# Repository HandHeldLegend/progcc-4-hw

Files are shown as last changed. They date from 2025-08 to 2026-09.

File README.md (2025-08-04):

# progcc-4-hw
Official repository for ProGCC 4 Hardware.

## 3D Models License
<br />The 3D CAD files are licensed under a <a rel="license" href="http://creativecommons.org/licenses/by/4.0/">Creative Commons Attribution 4.0 International License</a>.

## Schematic and PCB License
<br />This PCB and electronic schematic are licensed under a <a rel="license" href="http://creativecommons.org/licenses/by-nc-sa/3.0/">Creative Commons Attribution-NonCommercial-ShareAlike 3.0 Unported License</a>.

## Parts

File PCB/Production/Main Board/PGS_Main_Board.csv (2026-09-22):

Reference | Qty | Value | Footprint | Manufacturer | MPN | DNP | LCSC
C1,C2 | 2 | 15pF | Capacitor_SMD:C_0402_1005Metric | YAGEO | CC0402FRNPO9BN150 |  | C326803
C3,C4,C5,C6,C7,C8,C17,C18,C19,C29,C30,C31,C32,C33,C34,C35,C36,C37,C38 | 19 | 100n | Capacitor_SMD:C_0201_0603Metric | muRata | GRM033R61A104KE15D |  | C76934
C9,C10,C24,C25,C26,C27 | 6 | 100nF | Capacitor_SMD:C_0201_0603Metric | Samsung Electro-Mechanics | CL03A104KQ3NNNC |  | C160831
C11,C12,C13,C14 | 4 | 1uF | Capacitor_SMD:C_0201_0603Metric | Murata Electronics | GRM033R60J105KEA2D |  | C76929
C23,C39,C40,C41 | 4 | 4.7u | Capacitor_SMD:C_0402_1005Metric | Samsung Electro-Mechanics | CL05A475KP5NRNC |  | C368809
D1,D2,D3,D4,D5,D6 | 6 | M7C | Diode_SMD:D_SOD-523 | LGE | B5819WT |  | C5364321
J1,J2 | 2 | SM02B-SURS-TF_LF__SN_ | hhl:JST_SM02B-SURS-TF_LF__SN_ | JST | SM02B-SURS-TF(LF)(SN) |  | C566239
J3,J5 | 2 | Molex 505110-0892 | hhl:5051100892 | MOLEX | 505110-0892 |  | C5902847
J7,J11 | 2 | Molex 505110-0592 | hhl:5051100592 | MOLEX | 505110-0592 |  | C3168457
J9 | 1 | Molex 505110-1792 | hhl:5051101792 | MOLEX | 505110-1792 |  | C6819458
L1 | 1 | 3.3u | hhl:L_pol_2016 | Abraco LLC | AOTA-B201610S3R3-101-T |  | C42411119
Q1,Q2 | 2 | MMBT2222A | Package_TO_SOT_SMD:SOT-23 | JSMSEMI | MMBT2222A |  | C916372
R1,R28,R29 | 3 | 1k | Resistor_SMD:R_0201_0603Metric | YAGEO
R3,R4,R12,R13,R14,R15,R16,R17,R18,R21,R22,R25,R26,R30,R31,R33,R34 | 17 | 27R | Resistor_SMD:R_0201_0603Metric | YAGEO | RC0201FR-0727RL |  | C273268
R5,R6 | 2 | 10k | Resistor_SMD:R_0201_0603Metric | YAGEO
R7,R8 | 2 | 100R | Resistor_SMD:R_0201_0603Metric | YAGEO
R9,R10 | 2 | 10R | Resistor_SMD:R_0201_0603Metric | YAGEO
R11 | 1 | 33 | Resistor_SMD:R_0201_0603Metric | YAGEO
RGB1,RGB2,RGB3,RGB4,RGB5,RGB6,RGB7,RGB8,RGB9,RGB10,RGB11,RGB12,RGB13,RGB14,RGB15,RGB16 | 16 | SK6805-EC-10 | hhl:SK6805-EC-10 | OPSCO Optoelectronics | SK6805-EC-10 |  | C22394946
SW3,SW4,SW5,SW6,SW7,SW8,SW9,SW10,SW11 | 9 | SW_Push | hhl:KSC-TE | C&K | KSC201J LFS |  | C221725
U1,U3,U6,U7,U8,U9,U10,U11 | 8 | HAL4395 | hhl:SOT-23-5L | Hallwee | HAL4395SO5 |  | C49165022
U2 | 1 | RP2350_80QFN | hhl:RP2350-QFN-80-1EP_10x10_P0.4mm_EP3.4x3.4mm_ThermalVias | Raspberry Pi | RP2354B |  | C39843328
U4,U5 | 2 | ST_LSM6 | hhl:LGA14 | STMicroelectronics | LSM6DSLTR |  | C126672
Y1 | 1 | ABM8-272-T3 | Crystal:Crystal_SMD_3225-4Pin_3.2x2.5mm | Abracon LLC | ABM8-272-T3 |  | C20625731

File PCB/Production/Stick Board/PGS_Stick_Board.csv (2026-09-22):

Reference | Qty | Value | Footprint | Manufacturer | MPN | LCSC | DNP
C1,C2 | 2 | 47nF | Capacitor_SMD:C_0402_1005Metric | YAGEO | CC0402KRX7R9BB473 | C272875
J1 | 1 | Molex 505110-0892 | hhl:5051100892 | MOLEX | 505110-0892 | C5902847
R1,R2 | 2 | 1k | Resistor_SMD:R_0201_0603Metric | YAGEO | RC0201FR-071KL | C138165
RGB1,RGB2,RGB3,RGB4 | 4 | SK6805-EC-10 | hhl:SK6805-EC-10 | OPSCO Optoelectronics | SK6805-EC-10 | C22394946
SW1 | 1 | GL1807SYAE-002 | hhl:GL1807SYAE | Gulikit | GL1807SYAE-002

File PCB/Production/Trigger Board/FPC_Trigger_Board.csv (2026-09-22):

Reference | Qty | Value | Datasheet | Footprint | Manufacturer | MPN | LCSC | DNP
C1,C2,C3,C4 | 4 | 100n |  | Capacitor_SMD:C_0201_0603Metric | muRata | GRM033R61A104KE15D | C76934
J1,J2 | 2 | Conn_01x05_Pin |  | hhl:505110-0592 Ribbon |  |  |  | DNP
U1,U2,U3,U4 | 4 | HAL4395 | https://www.lcsc.com/datasheet/C49165022.pdf | hhl:SOT-23-5L | Hallwee | HAL4395SO5 | C49165022

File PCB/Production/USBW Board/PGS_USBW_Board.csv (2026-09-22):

Reference | Qty | Value | Footprint | Manufacturer | MPN | LCSC | DNP | Reviewed
C1 | 1 | 47uF | Capacitor_Tantalum_SMD:CP_EIA-3216-18_Kemet-A | Kyocera AVX | TAJA476K006RNJ | C7190 |  | Yes
C2,C4 | 2 | 10uF | Capacitor_SMD:C_0805_2012Metric | Samsung Electro-Mechanics | CL21A106KPFNNNE | C17024 |  | Yes
C3 | 1 | 100nF | Capacitor_SMD:C_0201_0603Metric | Samsung Electro-Mechanics | CL03A104KQ3NNNC | C160831 |  | Yes
C7,C14 | 2 | 1uF | Capacitor_SMD:C_0201_0603Metric | Murata Electronics | GRM033R60J105KEA2D | C76929 |  | Yes
C15 | 1 | 0.47uF | Capacitor_SMD:C_0201_0603Metric | Murata Electronics | GRM033R60J474KE90D | C85926 |  | Yes
D1,D3,D4 | 3 | CUS08F30,H3F | Diode_SMD:D_SOD-323_HandSoldering | TOSHIBA | CUS08F30,H3F | C150183 |  | Yes
IC1 | 1 | BQ27621YZFR-G1A | hhl:BGA9C50P3X3_162X158X62 | Texas Instruments | BQ27621YZFR-G1A | C544417 |  | Yes
J1 | 1 | Molex 505110-1792 | hhl:5051101792 | MOLEX | 505110-1792 | C6819458 |  | Yes
J2 | 1 | USB4056-03-A | hhl:USB405603A | Global Connector Technology | USB4056-03-A | C7407280 |  | Yes
J4 | 1 | PH 2.0 JST | Connector_JST:JST_PH_B2B-PH-K_1x02_P2.00mm_Vertical | JST | B2B-PH-K-K(LF)(SN) | C265438 |  | Yes
L1 | 1 | 1.3A 2.2uH ±20% 80mΩ | Inductor_SMD:L_1008_2520Metric | INPAQ | MIP25202R2MBE | C315721 |  | Yes
L2 | 1 | BLM18AG601SN1D | Inductor_SMD:L_0603_1608Metric | Murata Electronics | BLM18AG601SN1D | C19330 |  | Yes
P1 | 1 | RPI-RM2 | hhl:RPI_RM2 | Raspberry Pi | RPI-RM2
Q1,Q2 | 2 | BSS138DW | Package_TO_SOT_SMD:SOT-363_SC-70-6 | Diodes Incorporated | BSS138DW-7-F | C154900 |  | Yes
R1,R2 | 2 | 5.1k | Resistor_SMD:R_0201_0603Metric | YAGEO | RC0201FR-075K1L | C274341 |  | Yes
R3,R4,R5,R6,R7,R8 | 6 | 1k | Resistor_SMD:R_0201_0603Metric | YAGEO | RC0201FR-071KL | C138165 |  | Yes
R9 | 1 | 100R | Resistor_SMD:R_0201_0603Metric | YAGEO | RC0201FR-07100RL | C77623 |  | Yes
R10 | 1 | 0R | Resistor_SMD:R_0201_0603Metric | YAGEO | RC0201FR-070RL | C106227 |  | Yes
R12,R13,R20,R29 | 4 | 10k | Resistor_SMD:R_0201_0603Metric | YAGEO | RC0201FR-0710KL | C106225 |  | Yes
R14 | 1 | 470R | Resistor_SMD:R_0201_0603Metric | YAGEO | AC0201FR-07470RL | C226558 |  | Yes
R38 | 1 | 100k | Resistor_SMD:R_0402_1005Metric |  | RC0402FR-07100KL | C60491
U1,U2,U3 | 3 | USBLC6-2P6 | Package_TO_SOT_SMD:SOT-666 | TECH PUBLIC | USBLC6-2P6 | C2827693 |  | Yes
U5 | 1 | BQ25180 | hhl:DSBGA | Texas Instruments | BQ25180YBGR | C3682423 |  | Yes
U4 | 1 | TPS63001DRCR | hhl:VREG_V62_16624-01YE | Texas Instruments | TPS63001DRCR | C28060 |  | Yes

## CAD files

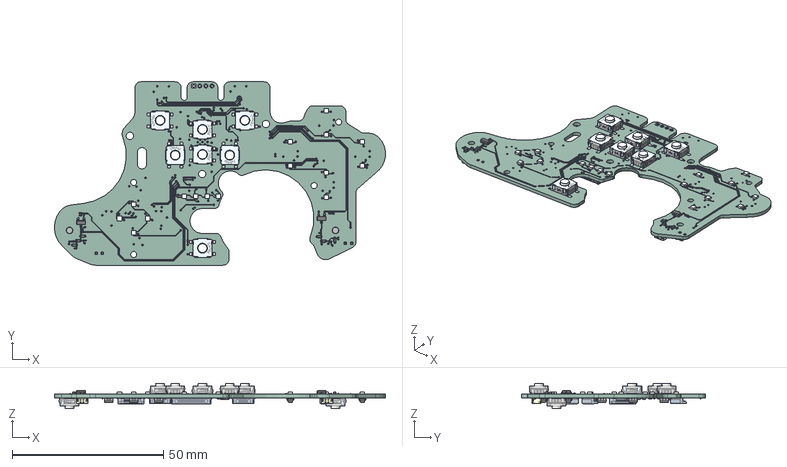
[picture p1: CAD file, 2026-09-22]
3D/PCB/PGS_Main_Board.step
109.5 x 60.7 x 8.33 mm
R_0201_0603Metric x 27
SK6805-EC15-3D v2 x 16
D_SOD_523 x 6
KSC2TE01JLFS_PART1 x 9
C_0201_0603Metric x 29
SOT-23 x 2
C_0402_1005Metric x 6
SOT-23-5 x 8
SM02B-SURS-TF(LF)(SN) x 2
Crystal_SMD_3225-4Pin_3.2x2.5mm
PGS_Main_Board_copper
PGS_Main_Board_pad
PGS_Main_Board_via
PGS_Main_Board_PCB

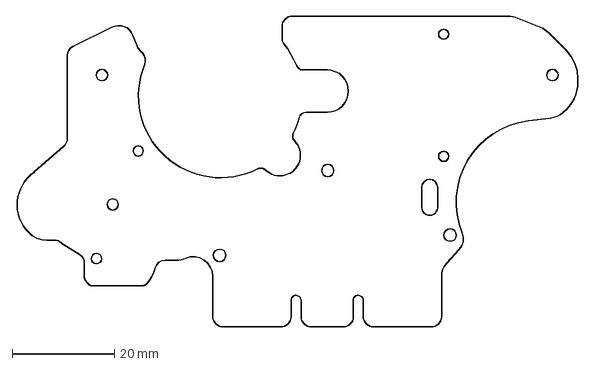
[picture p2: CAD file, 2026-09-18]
PCB/Outlines/Main_PCB_Outline.dxf
109.7 x 60.7 mm

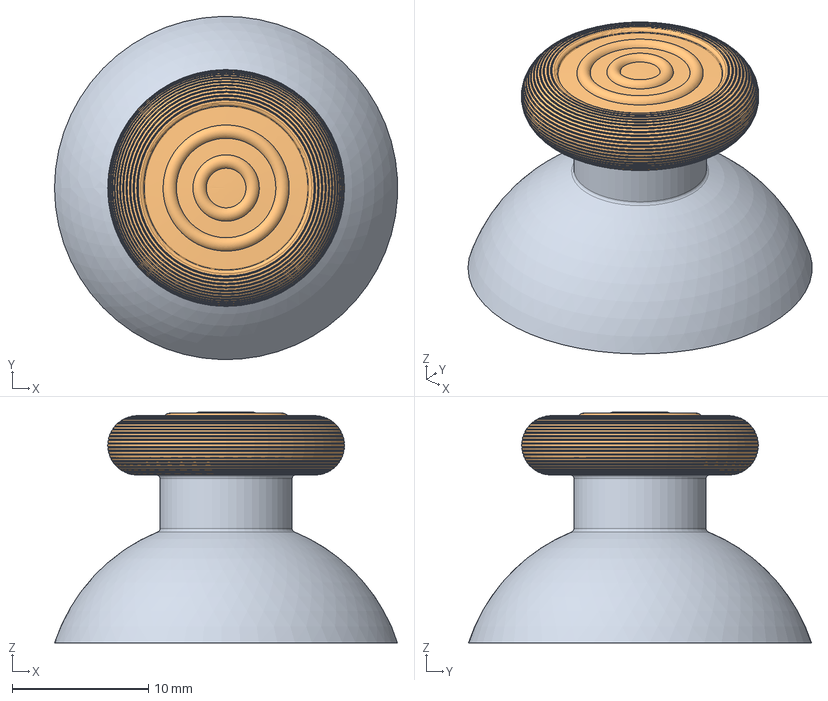
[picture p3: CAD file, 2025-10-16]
3D/Joystick/FullStick.step
25.1 x 25.1 x 16.9 mm
PlasticPart
RubberPart

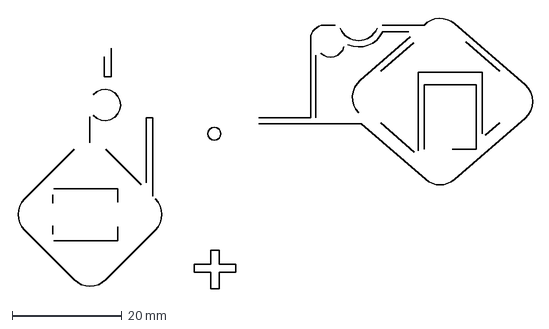
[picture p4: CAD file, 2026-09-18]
PCB/Outlines/Main_PCB_Keepout_Back.dxf
94.0 x 49.7 mm

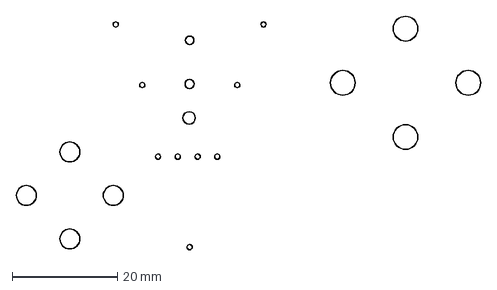
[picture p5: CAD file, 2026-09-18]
PCB/Outlines/Main_PCB_Components.dxf
88.1 x 44.3 mm

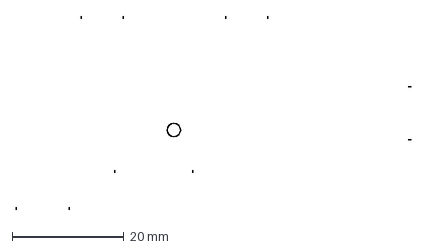
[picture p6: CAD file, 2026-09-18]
PCB/Outlines/Main_PCB_Connectors.dxf
70.7 x 34.7 mm

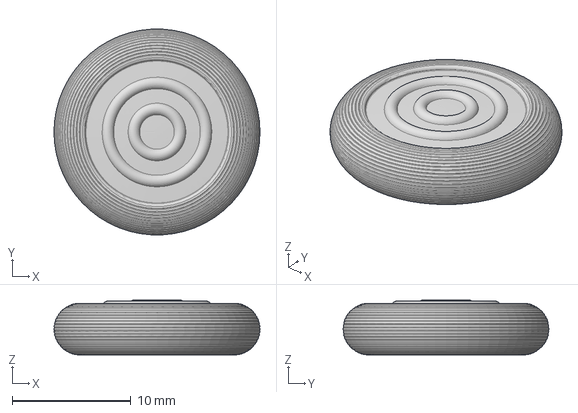
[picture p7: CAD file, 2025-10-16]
3D/Joystick/RubberPart.step
17.3 x 17.3 x 4.62 mm

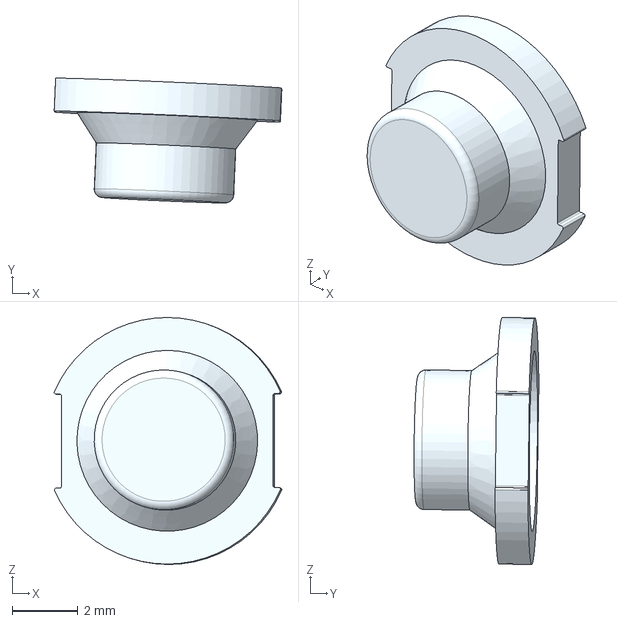
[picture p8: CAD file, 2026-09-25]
3D/STEP/Silicone Trigger (4pc needed).step
6.93 x 3.80 x 7.51 mm

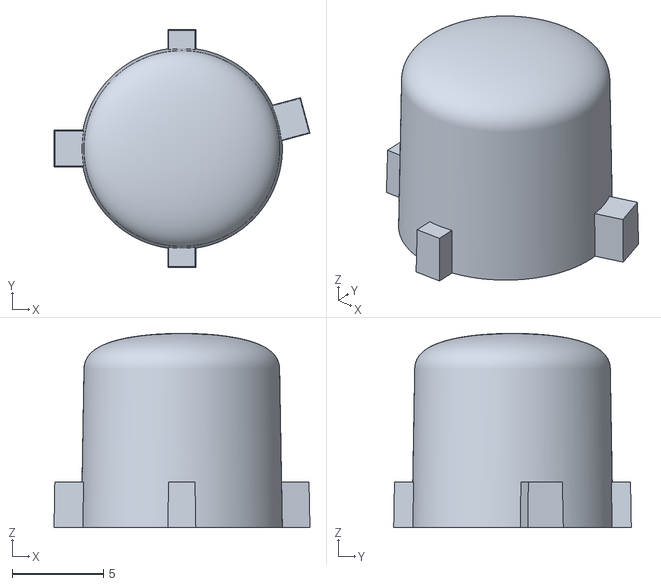
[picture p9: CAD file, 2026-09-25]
3D/STL/Button West Body.stl
14.0 x 13.0 x 10.6

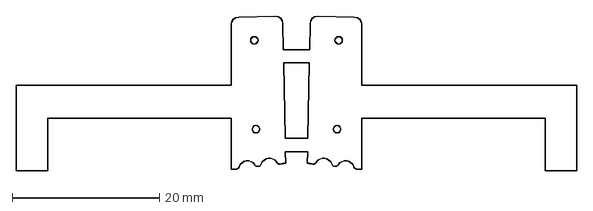
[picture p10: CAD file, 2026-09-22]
PCB/Outlines/Trigger OutlinePlace.dxf
76.2 x 21.0 mm

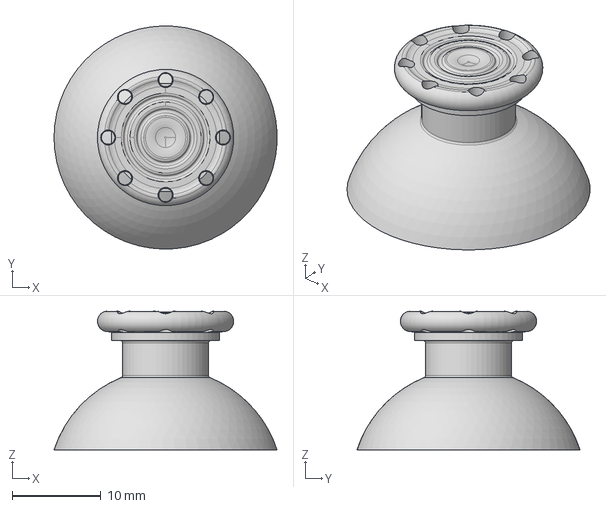
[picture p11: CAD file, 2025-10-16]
3D/Joystick/PlasticPart.step
25.1 x 25.1 x 15.6 mm

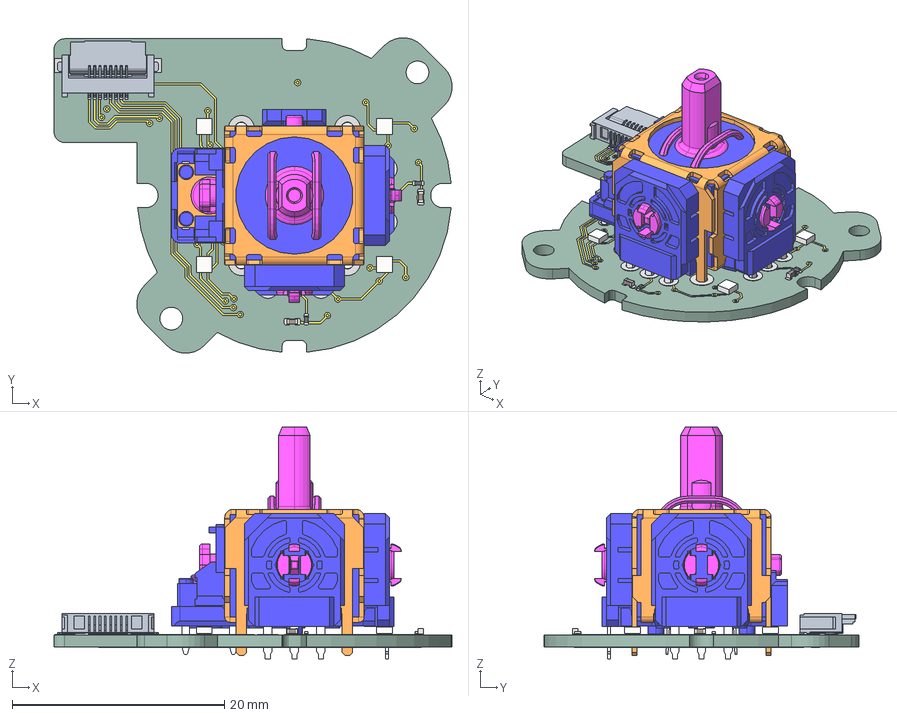
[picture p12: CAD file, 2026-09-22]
3D/PCB/PGS_Stick_Board.step
37.5 x 29.7 x 21.9 mm
SK6805-EC15-3D v2 x 4
R_0201_0603Metric x 2
C_0402_1005Metric x 2
PGSAFB4_copper
PGSAFB4_pad
PGSAFB4_via
PGSAFB4_PCB

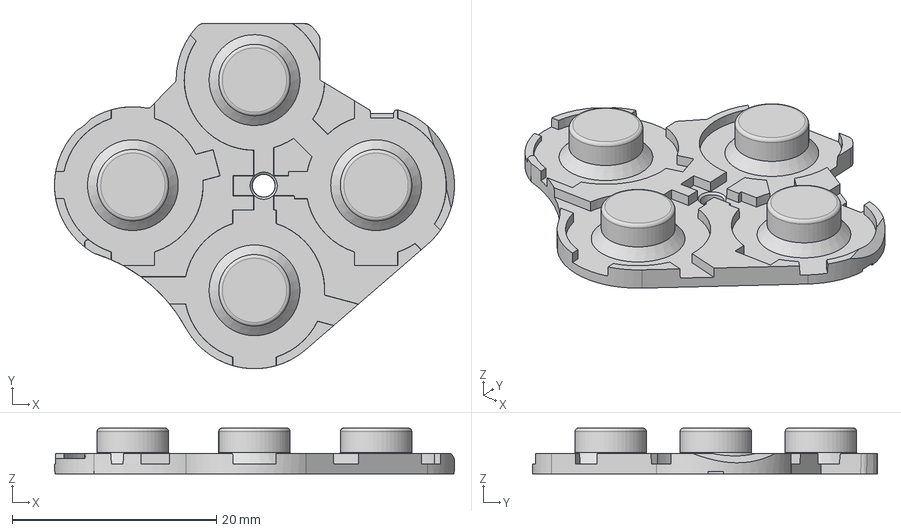
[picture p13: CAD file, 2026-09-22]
3D/STEP/Silicone SEWN.step
39.1 x 33.8 x 4.50 mm

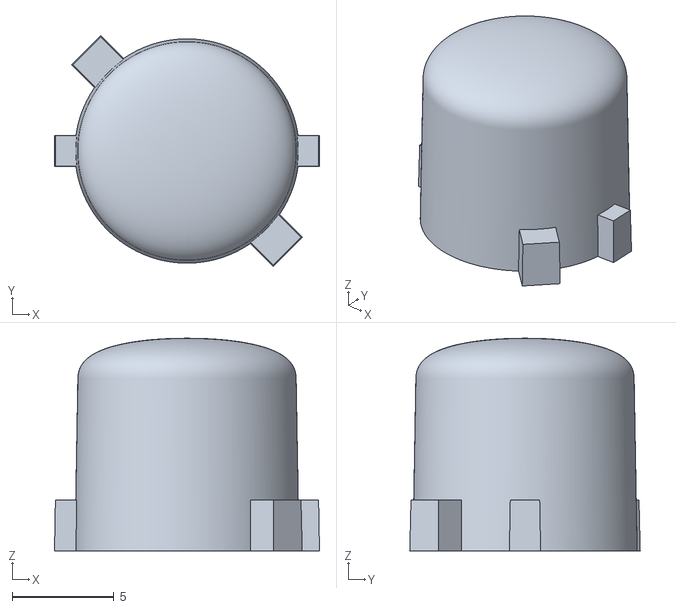
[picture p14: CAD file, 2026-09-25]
3D/STL/Button North Body.stl
13.0 x 11.3 x 10.5

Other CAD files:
3D/PCB/PGS_USBW_Board.step
3D/STEP/Silicone DPad.step
3D/STL/DPad Body.stl
3D/STL/Button South Body.stl
3D/Joystick/FullStick.iges
3D/Joystick/PlasticPart.iges
3D/Joystick/RubberPart.iges
3D/STL/Button East Body.stl
3D/STL/GL Button.stl
3D/STL/GR Button.stl
3D/STL/Gateplate Octagonal.stl
3D/STL/Gateplate Round.stl
3D/STL/Menu Button.stl
3D/STL/Player Lightpipe.stl
3D/STL/Power Button.stl
3D/STL/Shell Lower Body.stl
3D/STL/Shell Middle Body.stl
3D/STL/Shell Top Body.stl
3D/STL/Support Frame.stl
3D/STL/Trigger Bracket.stl
3D/STL/Triggers Body.stl
PCB/Outlines/Stick_Module_Export.dxf
PCB/Outlines/Trigger_Board_Export.dxf
PCB/Outlines/USB_Board_Export.dxf

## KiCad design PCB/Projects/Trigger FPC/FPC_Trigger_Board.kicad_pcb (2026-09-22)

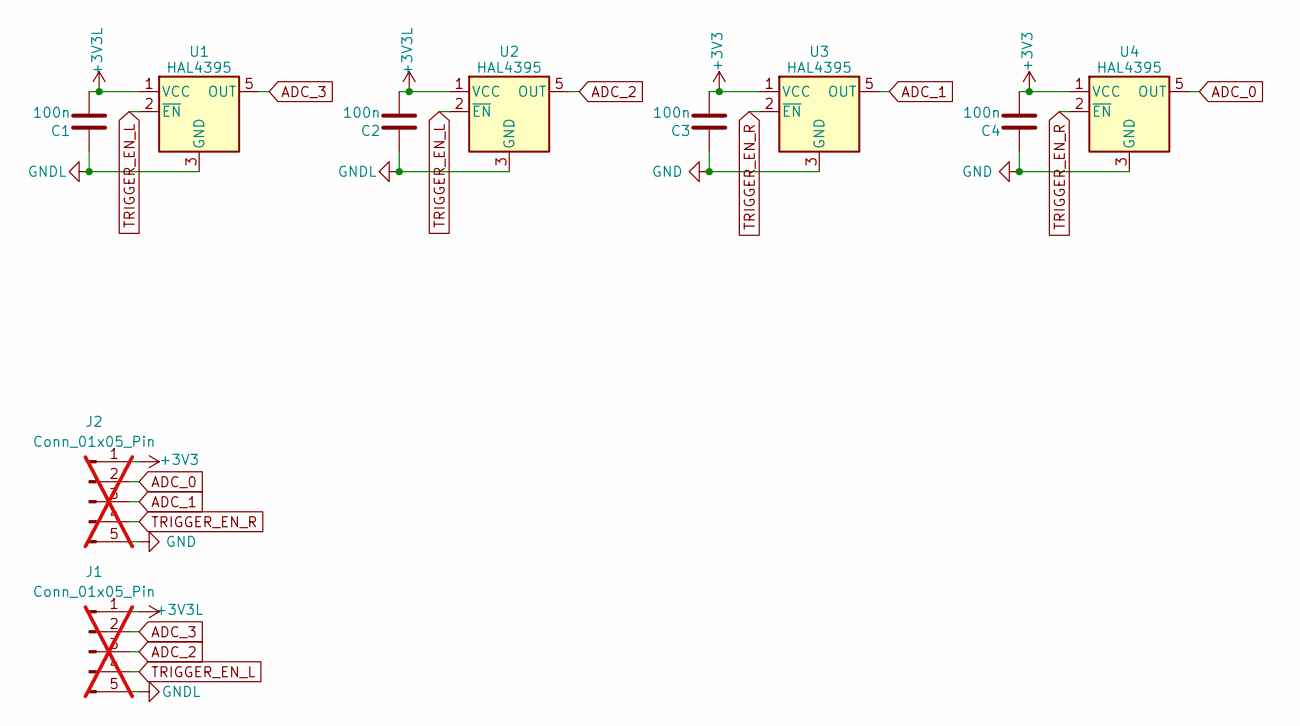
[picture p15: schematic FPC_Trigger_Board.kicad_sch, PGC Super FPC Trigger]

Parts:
C1, C2, C3, C4: 100n; C_0201_0603Metric; MPN GRM033R61A104KE15D; LCSC C76934
J1, J2: Conn_01x05_Pin; 505110-0592 Ribbon; not fitted
U1, U2, U3, U4: HAL4395; SOT-23-5L; MPN HAL4395SO5; LCSC C49165022

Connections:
+3V3: C3.2, C4.2, J2.1, U3.1 (VCC), U4.1 (VCC)
+3V3L: C1.2, C2.2, J1.1, U1.1 (VCC), U2.1 (VCC)
ADC_0: J2.2, U4.5 (OUT)
ADC_1: J2.3, U3.5 (OUT)
ADC_2: J1.3, U2.5 (OUT)
ADC_3: J1.2, U1.5 (OUT)
GND: C3.1, C4.1, J2.5, U3.3 (GND), U4.3 (GND)
GNDL: C1.1, C2.1, J1.5, U1.3 (GND), U2.3 (GND)
TRIGGER_EN_L: J1.4, U1.2 (~EN), U2.2 (~EN)
TRIGGER_EN_R: J2.4, U3.2 (~EN), U4.2 (~EN)

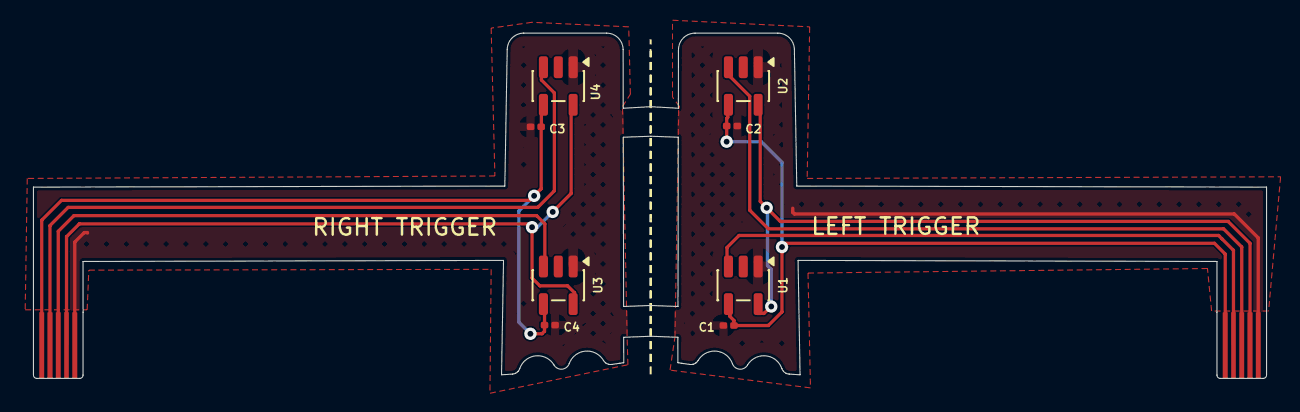
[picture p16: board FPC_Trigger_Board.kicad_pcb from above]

Board: 2 copper layers, 74.6 x 20.9 mm, 10 parts (2 on the bottom side), 10 nets.

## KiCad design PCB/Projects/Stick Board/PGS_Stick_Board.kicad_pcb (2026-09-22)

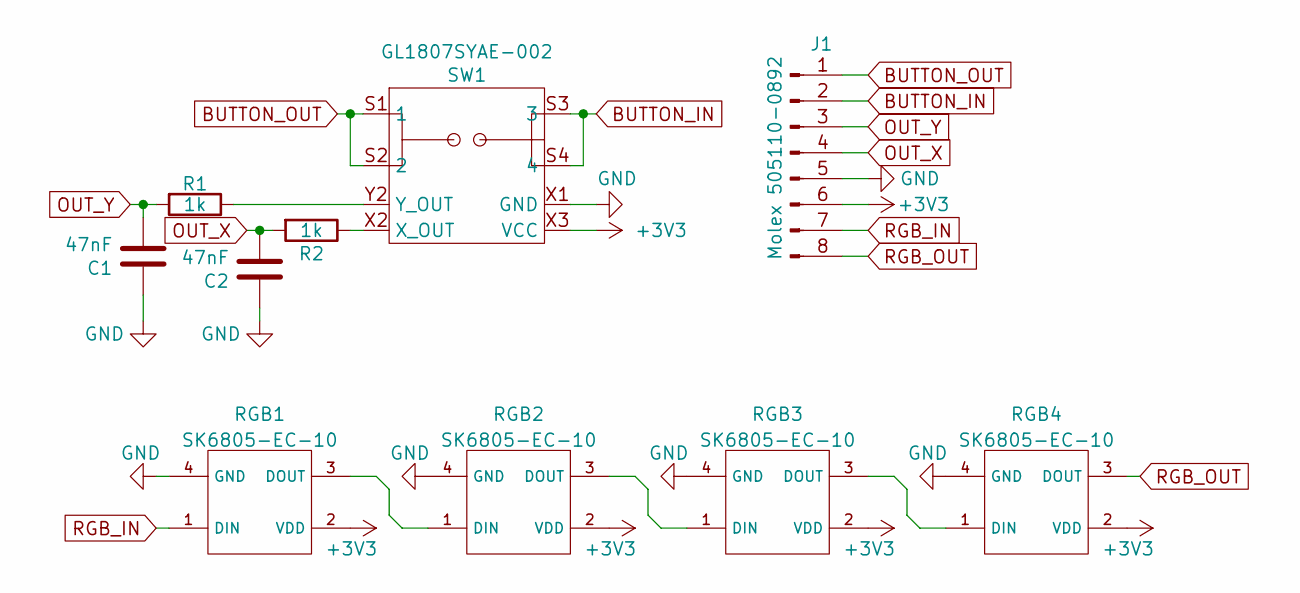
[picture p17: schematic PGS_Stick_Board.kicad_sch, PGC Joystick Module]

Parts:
C1, C2: 47nF; C_0402_1005Metric; MPN CC0402KRX7R9BB473; LCSC C272875
J1: Molex 505110-0892; 5051100892; MPN 505110-0892; LCSC C5902847
R1, R2: 1k; R_0201_0603Metric; MPN RC0201FR-071KL; LCSC C138165
RGB1, RGB2, RGB3, RGB4: SK6805-EC-10; MPN SK6805-EC-10; LCSC C22394946
SW1: GL1807SYAE-002; GL1807SYAE; MPN GL1807SYAE-002

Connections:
+3V3: J1.6, RGB1.2 (VDD), RGB2.2 (VDD), RGB3.2 (VDD), RGB4.2 (VDD), SW1.X3 (VCC), SW1.Y3 (VCC)
BUTTON_IN: J1.2, SW1.S3 (3), SW1.S4 (4)
BUTTON_OUT: J1.1, SW1.S1 (1), SW1.S2 (2)
GND: C1.1, C2.1, J1.5, RGB1.4 (GND), RGB2.4 (GND), RGB3.4 (GND), RGB4.4 (GND), SW1.X1 (GND), SW1.Y1 (GND)
unnamed: RGB1.3 (DOUT), RGB2.1 (DIN)
unnamed: RGB2.3 (DOUT), RGB3.1 (DIN)
unnamed: RGB3.3 (DOUT), RGB4.1 (DIN)
unnamed: R2.1, SW1.X2 (X_OUT)
unnamed: R1.1, SW1.Y2 (Y_OUT)
OUT_X: C2.2, J1.4, R2.2
OUT_Y: C1.2, J1.3, R1.2
RGB_IN: J1.7, RGB1.1 (DIN)
RGB_OUT: J1.8, RGB4.3 (DOUT)

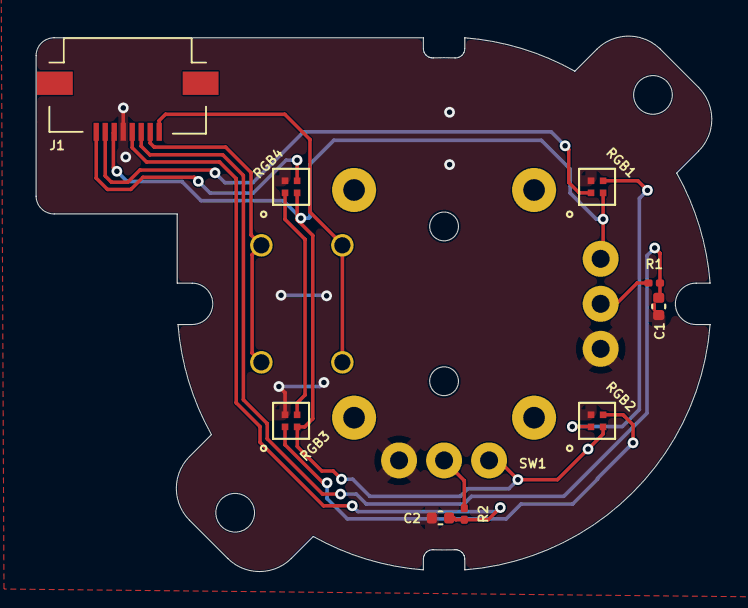
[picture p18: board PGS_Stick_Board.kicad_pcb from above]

Board: 2 copper layers, 37.5 x 29.7 mm, 10 parts (0 on the bottom side), 13 nets.

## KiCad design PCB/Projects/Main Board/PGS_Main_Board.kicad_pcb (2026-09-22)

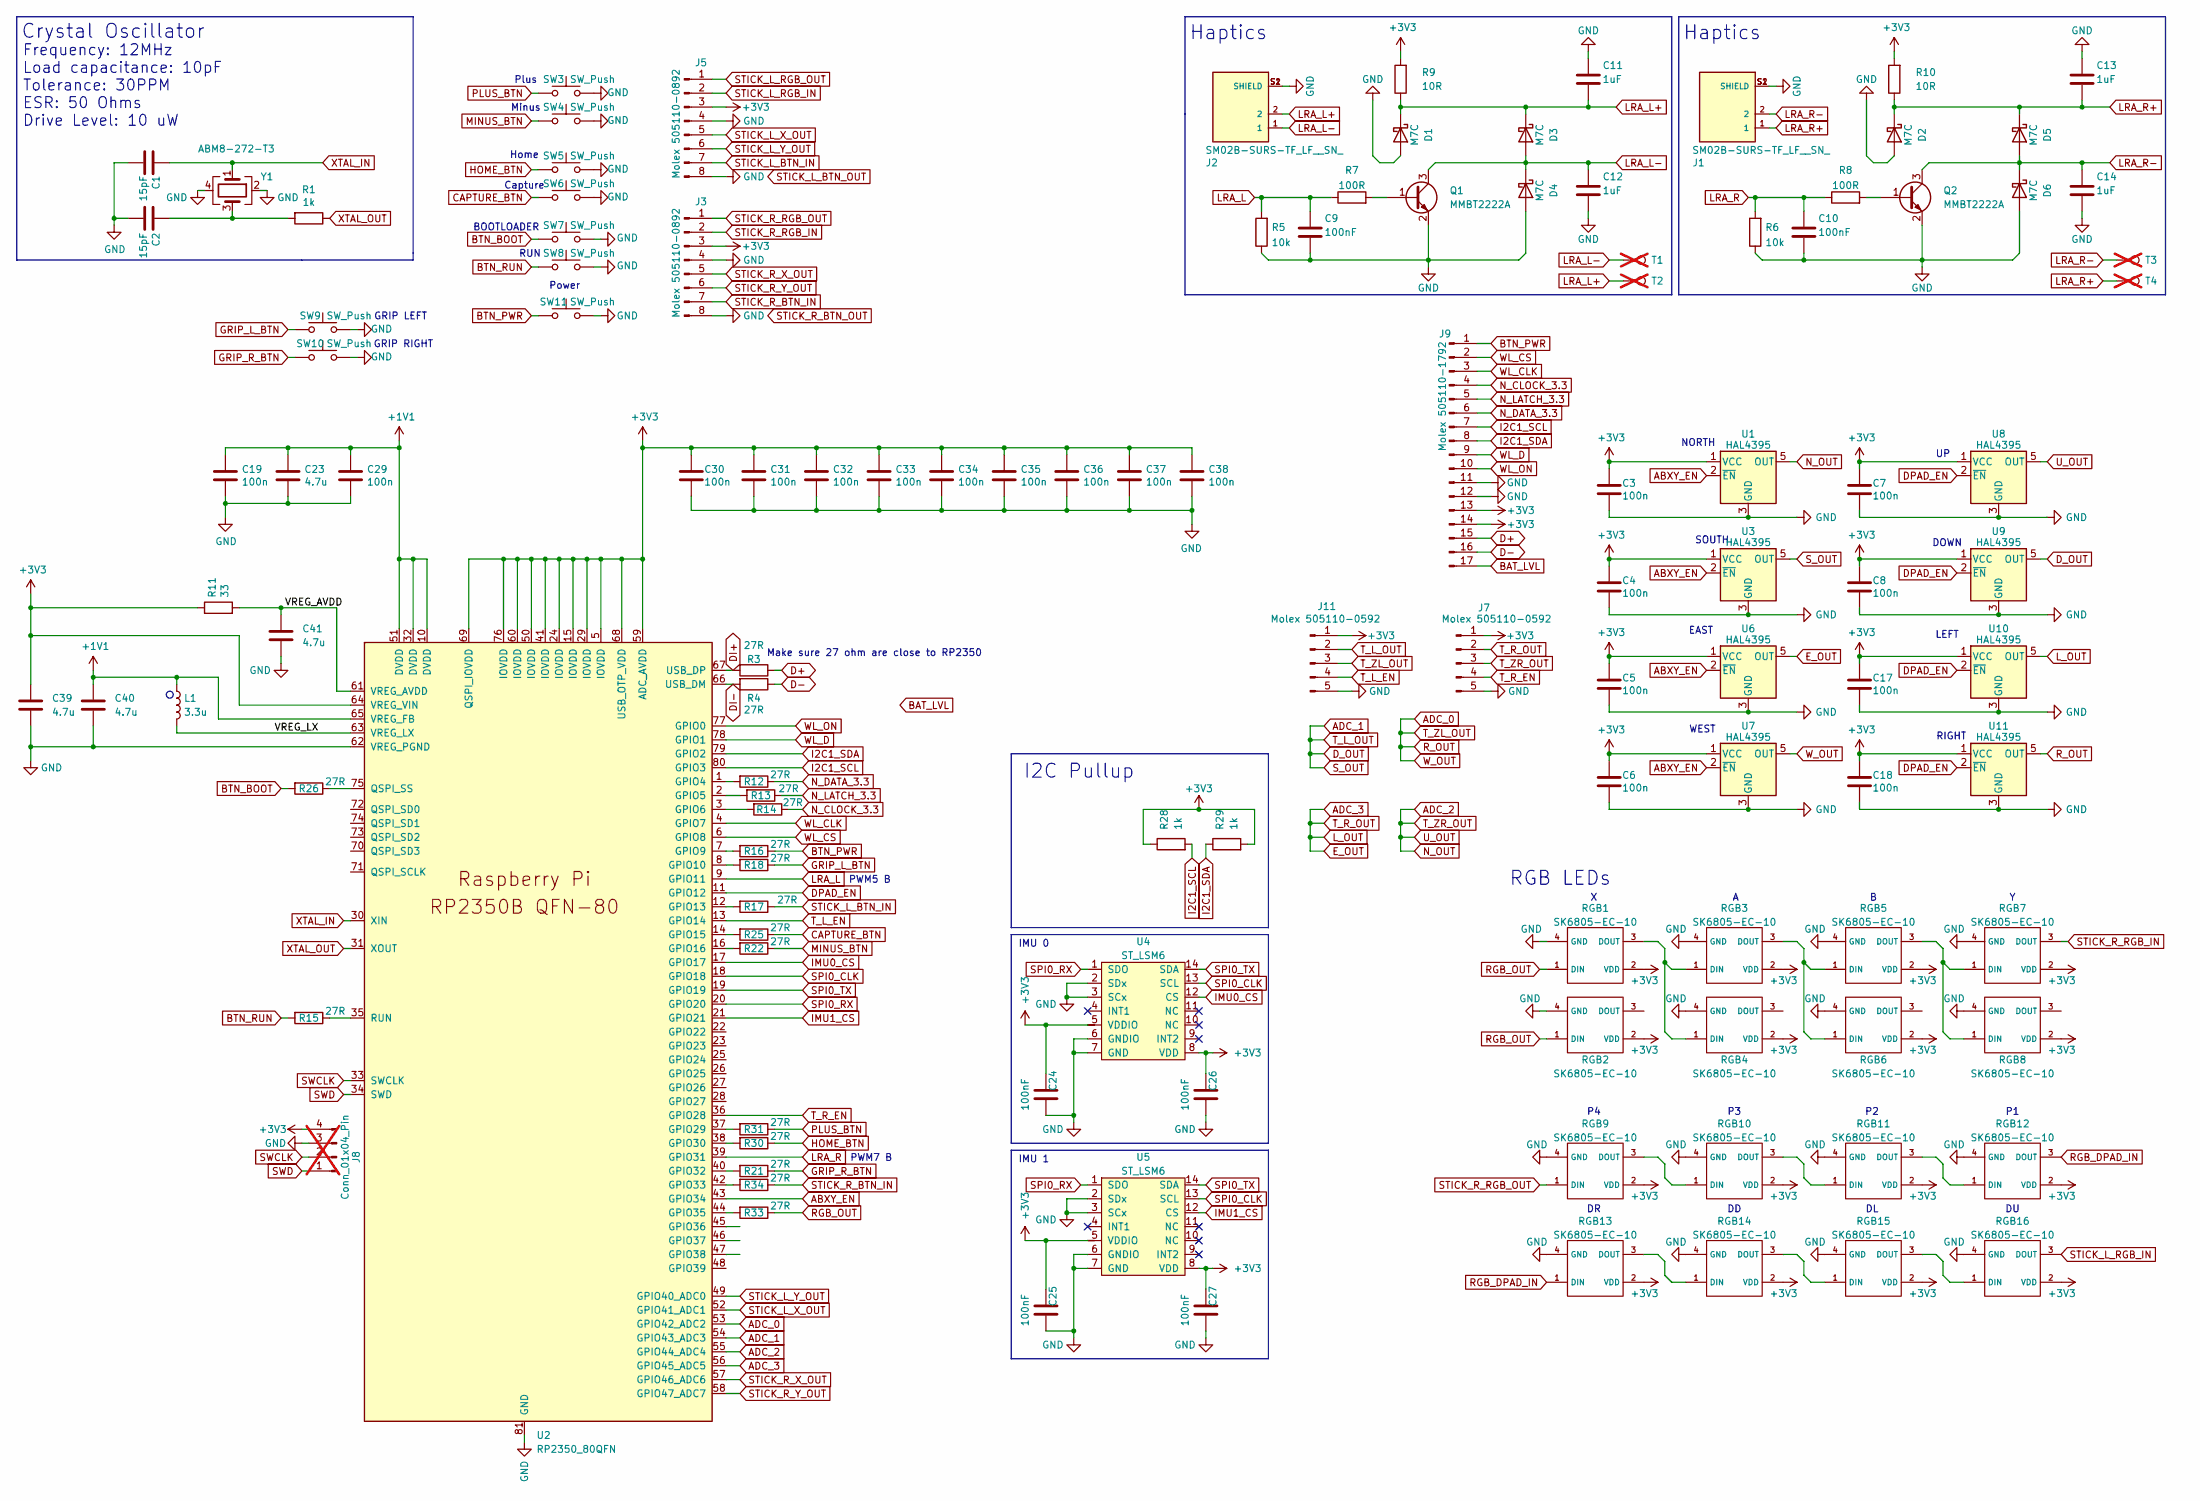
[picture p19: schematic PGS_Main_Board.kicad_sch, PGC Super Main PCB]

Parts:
C1, C2: 15pF; C_0402_1005Metric; MPN CC0402FRNPO9BN150; LCSC C326803
C3, C4, C5, C6, C7, C8, C17, C18, C19, C29, C30, C31, C32, C33, C34, C35, C36, C37, C38: 100n; C_0201_0603Metric; MPN GRM033R61A104KE15D; LCSC C76934
C9, C10, C24, C25, C26, C27: 100nF; C_0201_0603Metric; MPN CL03A104KQ3NNNC; LCSC C160831
C11, C12, C13, C14: 1uF; C_0201_0603Metric; MPN GRM033R60J105KEA2D; LCSC C76929
C23, C39, C40, C41: 4.7u; C_0402_1005Metric; MPN CL05A475KP5NRNC; LCSC C368809
D1, D2, D3, D4, D5, D6: M7C; D_SOD-523; MPN B5819WT; LCSC C5364321
J1, J2: SM02B-SURS-TF_LF__SN_; JST_SM02B-SURS-TF_LF__SN_; PARTREV N/A; LCSC C566239
J3, J5: Molex 505110-0892; 5051100892; MPN 505110-0892; LCSC C5902847
J7, J11: Molex 505110-0592; 5051100592; MPN 505110-0592; LCSC C3168457
J8: Conn_01x04_Pin; PinHeader_1x04_P2.00mm_Vertical; not fitted
J9: Molex 505110-1792; 5051101792; MPN 505110-1792; LCSC C6819458
L1: 3.3u; L_pol_2016; MPN AOTA-B201610S3R3-101-T; LCSC C42411119
Q1, Q2: MMBT2222A; SOT-23; MPN MMBT2222A; LCSC C916372
R1, R28, R29: 1k; R_0201_0603Metric
R3, R4, R12, R13, R14, R15, R16, R17, R18, R21, R22, R25, R26, R30, R31, R33, R34: 27R; R_0201_0603Metric; MPN RC0201FR-0727RL; LCSC C273268
R5, R6: 10k; R_0201_0603Metric
R7, R8: 100R; R_0201_0603Metric
R9, R10: 10R; R_0201_0603Metric
R11: 33; R_0201_0603Metric
RGB1, RGB2, RGB3, RGB4, RGB5, RGB6, RGB7, RGB8, RGB9, RGB10, RGB11, RGB12, RGB13, RGB14, RGB15, RGB16: SK6805-EC-10; MPN SK6805-EC-10; LCSC C22394946
SW3, SW4, SW5, SW6, SW7, SW8, SW9, SW10, SW11: SW_Push; KSC-TE; MPN KSC201J LFS; LCSC C221725
T1, T2, T3, T4: PinHeader_1x01_P1.00mm_Vertical; not fitted
U1, U3, U6, U7, U8, U9, U10, U11: HAL4395; SOT-23-5L; MPN HAL4395SO5; LCSC C49165022
U2: RP2350_80QFN; RP2350-QFN-80-1EP_10x10_P0.4mm_EP3.4x3.4mm_ThermalVias; MPN RP2354B; LCSC C39843328
U4, U5: ST_LSM6; LGA14; MPN LSM6DSLTR; LCSC C126672
Y1: ABM8-272-T3; Crystal_SMD_3225-4Pin_3.2x2.5mm; MPN ABM8-272-T3; LCSC C20625731

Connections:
+1V1: C19.1, C23.1, C29.1, C40.1, L1.1, U2.10 (DVDD), U2.32 (DVDD), U2.51 (DVDD), U2.65 (VREG_FB)
+3V3: C3.1, C4.1, C5.1, C6.1, C7.1, C8.1, C17.1, C18.1, C24.2, C25.2, C26.2, C27.2, C30.1, C31.1, C32.1, C33.1, C34.1, C35.1, C36.1, C37.1, C38.1, C39.1, J3.3, J5.3, J7.1, J8.4, J9.13, J9.14, J11.1, R9.2, R10.2, R11.1, R28.1, R29.2, RGB1.2 (VDD), RGB2.2 (VDD), RGB3.2 (VDD), RGB4.2 (VDD), RGB5.2 (VDD), RGB6.2 (VDD), RGB7.2 (VDD), RGB8.2 (VDD), RGB9.2 (VDD), RGB10.2 (VDD), RGB11.2 (VDD), RGB12.2 (VDD), RGB13.2 (VDD), RGB14.2 (VDD), RGB15.2 (VDD), RGB16.2 (VDD), U1.1 (VCC), U2.5 (IOVDD), U2.15 (IOVDD), U2.24 (IOVDD), U2.29 (IOVDD), U2.41 (IOVDD), U2.50 (IOVDD), U2.59 (ADC_AVDD), U2.60 (IOVDD), U2.64 (VREG_VIN), U2.68 (USB_OTP_VDD), U2.69 (QSPI_IOVDD), U2.76 (IOVDD), U3.1 (VCC), U4.5 (VDDIO), U4.8 (VDD), U5.5 (VDDIO), U5.8 (VDD), U6.1 (VCC), U7.1 (VCC), U8.1 (VCC), U9.1 (VCC), U10.1 (VCC), U11.1 (VCC)
/VREG_AVDD: C41.1, R11.2, U2.61 (VREG_AVDD)
/VREG_LX: L1.2, U2.63 (VREG_LX)
ABXY_EN: U1.2 (~EN), U2.43 (GPIO34), U3.2 (~EN), U6.2 (~EN), U7.2 (~EN)
ADC_0: J11.3, U2.53 (GPIO42_ADC2), U7.5 (OUT), U11.5 (OUT)
ADC_1: J11.2, U2.54 (GPIO43_ADC3), U3.5 (OUT), U9.5 (OUT)
ADC_2: J7.3, U1.5 (OUT), U2.55 (GPIO44_ADC4), U8.5 (OUT)
ADC_3: J7.2, U2.56 (GPIO45_ADC5), U6.5 (OUT), U10.5 (OUT)
BAT_LVL: J9.17
BTN_BOOT: R26.2, SW7.1
BTN_PWR: J9.1, R16.1, SW11.1
BTN_RUN: R15.2, SW8.1
CAPTURE_BTN: R25.1, SW6.1
D+: J9.15, R3.1
D-: J9.16, R4.1
DI+: R3.2, U2.67 (USB_DP)
DI-: R4.2, U2.66 (USB_DM)
DPAD_EN: U2.11 (GPIO12), U8.2 (~EN), U9.2 (~EN), U10.2 (~EN), U11.2 (~EN)
GND: C1.2, C2.2, C3.2, C4.2, C5.2, C6.2, C7.2, C8.2, C9.2, C10.2, C11.1, C12.2, C13.1, C14.2, C17.2, C18.2, C19.2, C23.2, C24.1, C25.1, C26.1, C27.1, C29.2, C30.2, C31.2, C32.2, C33.2, C34.2, C35.2, C36.2, C37.2, C38.2, C39.2, C40.2, C41.2, D1.2 (A), D2.2 (A), D4.2 (A), D6.2 (A), J1.S1 (SHIELD), J1.S2 (SHIELD), J2.S1 (SHIELD), J2.S2 (SHIELD), J3.4, J3.8, J5.4, J5.8, J7.5, J8.3, J9.11, J9.12, J11.5, Q1.2 (E), Q2.2 (E), R5.1, R6.1, RGB1.4 (GND), RGB2.4 (GND), RGB3.4 (GND), RGB4.4 (GND), RGB5.4 (GND), RGB6.4 (GND), RGB7.4 (GND), RGB8.4 (GND), RGB9.4 (GND), RGB10.4 (GND), RGB11.4 (GND), RGB12.4 (GND), RGB13.4 (GND), RGB14.4 (GND), RGB15.4 (GND), RGB16.4 (GND), SW3.2, SW4.2, SW5.2, SW6.2, SW7.2, SW8.2, SW9.2, SW10.2, SW11.2, U1.3 (GND), U2.62 (VREG_PGND), U2.81 (GND), U3.3 (GND), U4.2 (SDx), U4.3 (SCx), U4.6 (GNDIO), U4.7 (GND), U5.2 (SDx), U5.3 (SCx), U5.6 (GNDIO), U5.7 (GND), U6.3 (GND), U7.3 (GND), U8.3 (GND), U9.3 (GND), U10.3 (GND), U11.3 (GND), Y1.2, Y1.4
GRIP_L_BTN: R18.1, SW9.1
GRIP_R_BTN: R21.1, SW10.1
HOME_BTN: R30.1, SW5.1
I2C1_SCL: J9.7, R28.2, U2.80 (GPIO3)
I2C1_SDA: J9.8, R29.1, U2.79 (GPIO2)
IMU0_CS: U2.17 (GPIO17), U4.12 (CS)
IMU1_CS: U2.21 (GPIO21), U5.12 (CS)
LRA_L: C9.1, R5.2, R7.1, U2.9 (GPIO11)
LRA_L+: C11.2, D1.1 (K), D3.1 (K), J2.2, R9.1, T2.1 (1_1)
LRA_L-: C12.1, D3.2 (A), D4.1 (K), J2.1, Q1.3 (C), T1.1 (1_1)
LRA_R: C10.1, R6.2, R8.1, U2.39 (GPIO31)
LRA_R+: C13.2, D2.1 (K), D5.1 (K), J1.1, R10.1, T4.1 (1_1)
LRA_R-: C14.1, D5.2 (A), D6.1 (K), J1.2, Q2.3 (C), T3.1 (1_1)
MINUS_BTN: R22.1, SW4.1
N_CLOCK_3.3: J9.4, R14.1
N_DATA_3.3: J9.6, R12.1
N_LATCH_3.3: J9.5, R13.1
unnamed: C2.1, R1.2, Y1.3
unnamed: Q1.1 (B), R7.2
unnamed: Q2.1 (B), R8.2
unnamed: RGB1.3 (DOUT), RGB3.1 (DIN), RGB4.1 (DIN)
unnamed: RGB3.3 (DOUT), RGB5.1 (DIN), RGB6.1 (DIN)
unnamed: RGB5.3 (DOUT), RGB7.1 (DIN), RGB8.1 (DIN)
unnamed: RGB9.3 (DOUT), RGB10.1 (DIN)
unnamed: RGB10.3 (DOUT), RGB11.1 (DIN)
unnamed: RGB11.3 (DOUT), RGB12.1 (DIN)
unnamed: RGB13.3 (DOUT), RGB14.1 (DIN)
unnamed: RGB14.3 (DOUT), RGB15.1 (DIN)
unnamed: RGB15.3 (DOUT), RGB16.1 (DIN)
unnamed: R12.2, U2.1 (GPIO4)
unnamed: R13.2, U2.2 (GPIO5)
unnamed: R14.2, U2.3 (GPIO6)
unnamed: R16.2, U2.7 (GPIO9)
unnamed: R18.2, U2.8 (GPIO10)
unnamed: R17.2, U2.12 (GPIO13)
unnamed: R25.2, U2.14 (GPIO15)
unnamed: R22.2, U2.16 (GPIO16)
unnamed: R31.2, U2.37 (GPIO29)
unnamed: R30.2, U2.38 (GPIO30)
unnamed: R21.2, U2.40 (GPIO32)
unnamed: R34.2, U2.42 (GPIO33)
unnamed: R33.2, U2.44 (GPIO35)
unnamed: R26.1, U2.75 (QSPI_SS)
unnamed: R15.1, U2.35 (RUN)
PLUS_BTN: R31.1, SW3.1
RGB_DPAD_IN: RGB12.3 (DOUT), RGB13.1 (DIN)
RGB_OUT: R33.1, RGB1.1 (DIN), RGB2.1 (DIN)
SPI0_CLK: U2.18 (GPIO18), U4.13 (SCL), U5.13 (SCL)
SPI0_RX: U2.20 (GPIO20), U4.1 (SDO), U5.1 (SDO)
SPI0_TX: U2.19 (GPIO19), U4.14 (SDA), U5.14 (SDA)
STICK_L_BTN_IN: J5.7, R17.1
STICK_L_RGB_IN: J5.2, RGB16.3 (DOUT)
STICK_L_RGB_OUT: J5.1
STICK_L_X_OUT: J5.5, U2.52 (GPIO41_ADC1)
STICK_L_Y_OUT: J5.6, U2.49 (GPIO40_ADC0)
STICK_R_BTN_IN: J3.7, R34.1
STICK_R_RGB_IN: J3.2, RGB7.3 (DOUT)
STICK_R_RGB_OUT: J3.1, RGB9.1 (DIN)
STICK_R_X_OUT: J3.5, U2.57 (GPIO46_ADC6)
STICK_R_Y_OUT: J3.6, U2.58 (GPIO47_ADC7)
SWCLK: J8.2, U2.33 (SWCLK)
SWD: J8.1, U2.34 (SWD)
T_L_EN: J11.4, U2.13 (GPIO14)
T_R_EN: J7.4, U2.36 (GPIO28)
WL_CLK: J9.3, U2.4 (GPIO7)
WL_CS: J9.2, U2.6 (GPIO8)
WL_D: J9.9, U2.78 (GPIO1)
WL_ON: J9.10, U2.77 (GPIO0)
XTAL_IN: C1.1, U2.30 (XIN), Y1.1
XTAL_OUT: R1.1, U2.31 (XOUT)

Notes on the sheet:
Plus
Power
Home
IMU 0
Make sure 27 ohm are close to RP2350
Haptics
RGB LEDs
Crystal Oscillator
GRIP RIGHT
DOWN
GRIP LEFT
SOUTH
IMU 1
Capture
WEST
PWM7 B
I2C Pullup
BOOTLOADER
Frequency: 12MHz Load capacitance: 10pF Tolerance: 30PPM ESR: 50 Ohms Drive Level: 10 uW
PWM5 B
RUN
RIGHT
NORTH
LEFT
EAST
Minus

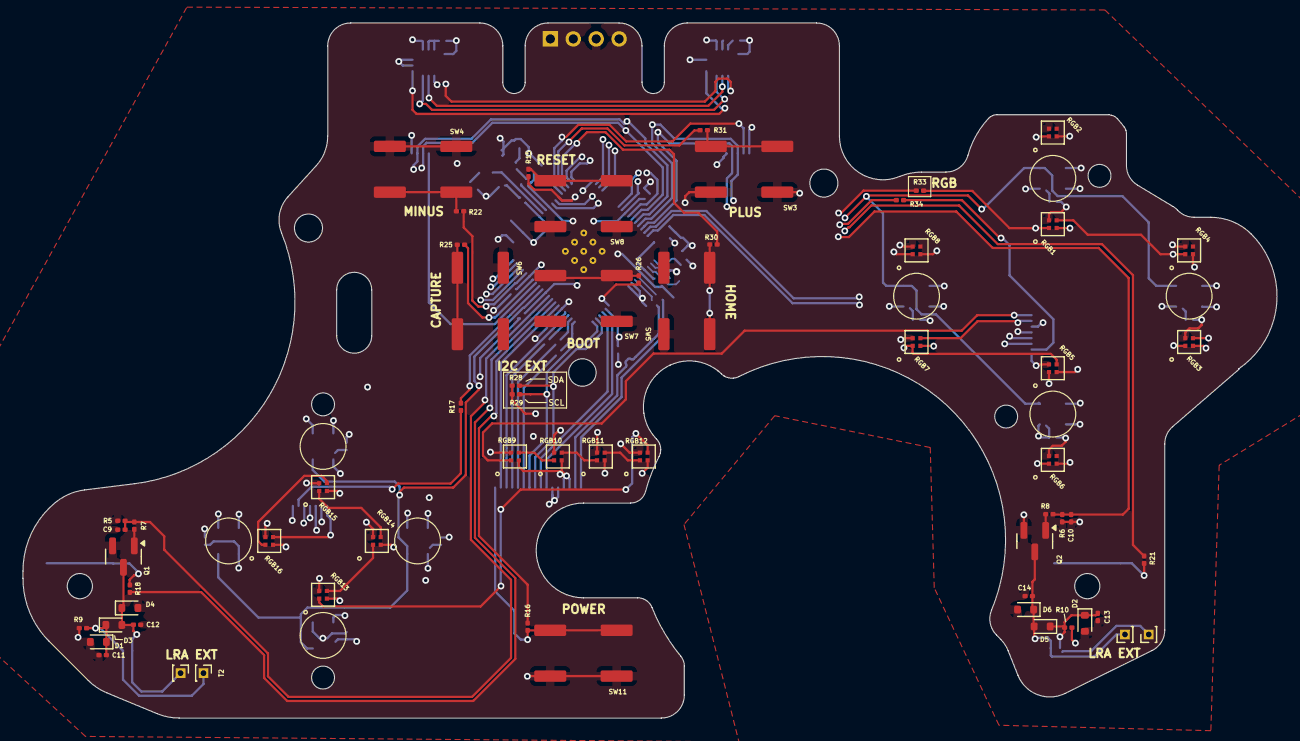
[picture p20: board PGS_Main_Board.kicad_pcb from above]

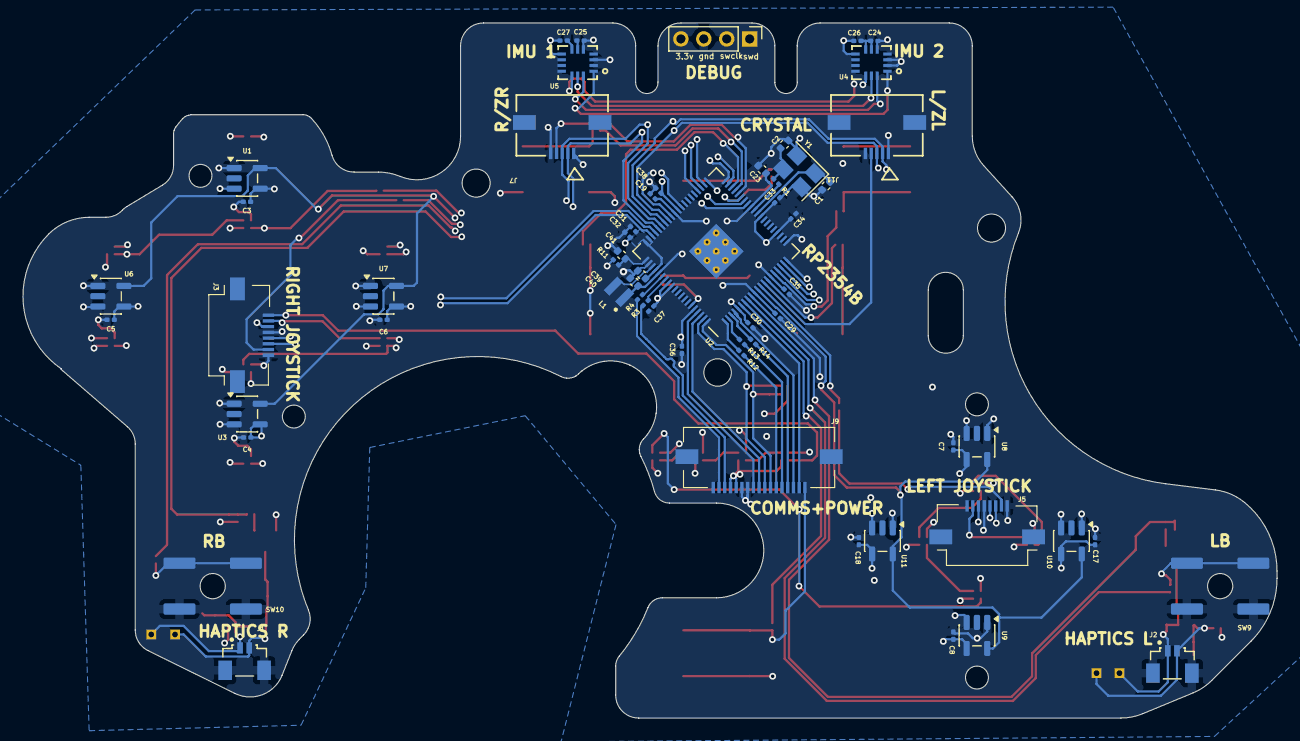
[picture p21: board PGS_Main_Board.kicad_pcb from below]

Board: 4 copper layers, 109.5 x 60.7 mm, 120 parts (59 on the bottom side), 88 nets.

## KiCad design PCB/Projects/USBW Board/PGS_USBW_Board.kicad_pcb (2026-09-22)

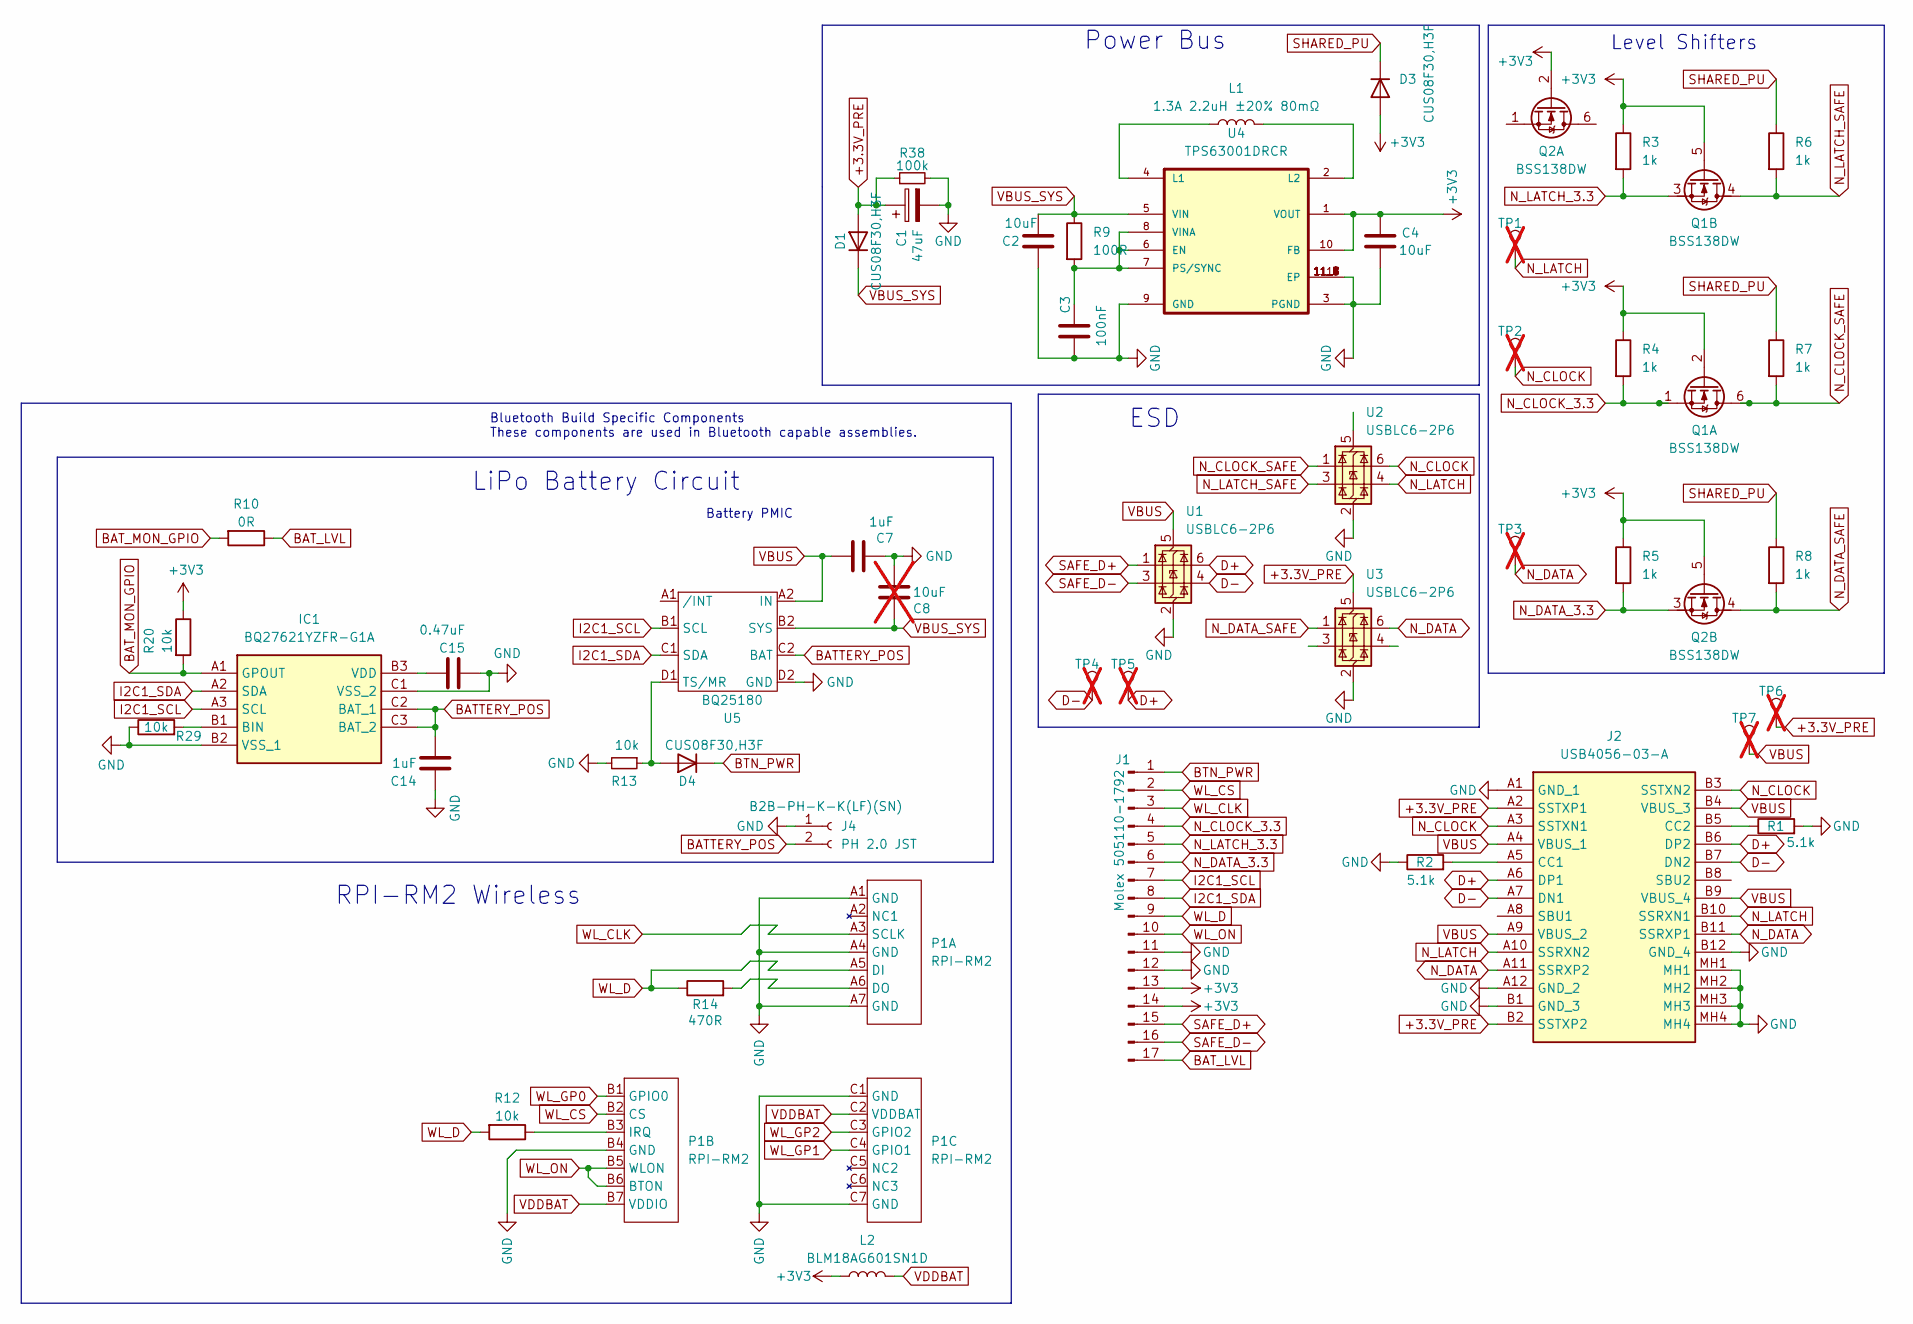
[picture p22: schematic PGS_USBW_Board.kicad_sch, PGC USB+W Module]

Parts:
C1: 47uF; CP_EIA-3216-18_Kemet-A; MPN TAJA476K006RNJ; LCSC C7190
C2, C4: 10uF; C_0805_2012Metric; MPN CL21A106KPFNNNE; LCSC C17024
C3: 100nF; C_0201_0603Metric; MPN CL03A104KQ3NNNC; LCSC C160831
C7, C14: 1uF; C_0201_0603Metric; MPN GRM033R60J105KEA2D; LCSC C76929
C8: 10uF; C_0805_2012Metric; MPN CL21A106KPFNNNE; LCSC C17024; not fitted
C15: 0.47uF; C_0201_0603Metric; MPN GRM033R60J474KE90D; LCSC C85926
D1, D3, D4: CUS08F30,H3F; D_SOD-323_HandSoldering; MPN CUS08F30,H3F; LCSC C150183
IC1: BQ27621YZFR-G1A; BGA9C50P3X3_162X158X62; Mouser Part Number 595-BQ27621YZFR-G1A
J1: Molex 505110-1792; 5051101792; MPN 505110-1792; LCSC C6819458
J2: USB4056-03-A; USB405603A; Mouser Part Number 640-USB4056-03-A
J4: PH 2.0 JST; JST_PH_B2B-PH-K_1x02_P2.00mm_Vertical; MPN B2B-PH-K-K(LF)(SN); LCSC C265438
L1: 1.3A 2.2uH ±20% 80mΩ; L_1008_2520Metric; MPN MIP25202R2MBE; LCSC C315721
L2: BLM18AG601SN1D; L_0603_1608Metric; MPN BLM18AG601SN1D; LCSC C19330
P1: RPI-RM2; RPI_RM2; MPN RPI-RM2
Q1, Q2: BSS138DW; SOT-363_SC-70-6; MPN BSS138DW-7-F; LCSC C154900
R1, R2: 5.1k; R_0201_0603Metric; MPN RC0201FR-075K1L; LCSC C274341
R3, R4, R5, R6, R7, R8: 1k; R_0201_0603Metric; MPN RC0201FR-071KL; LCSC C138165
R9: 100R; R_0201_0603Metric; MPN RC0201FR-07100RL; LCSC C77623
R10: 0R; R_0201_0603Metric; MPN RC0201FR-070RL; LCSC C106227
R12, R13, R20, R29: 10k; R_0201_0603Metric; MPN RC0201FR-0710KL; LCSC C106225
R14: 470R; R_0201_0603Metric; MPN AC0201FR-07470RL; LCSC C226558
R38: 100k; R_0402_1005Metric; MPN RC0402FR-07100KL; LCSC C60491
TP1, TP2, TP3, TP4, TP5, TP6, TP7: TestPoint; TestPoint_Pad_D1.0mm; not fitted
U1, U2, U3: USBLC6-2P6; SOT-666; MPN USBLC6-2P6; LCSC C2827693
U4: TPS63001DRCR; VREG_V62_16624-01YE; MPN TPS63001DRCR; LCSC C28060
U5: BQ25180; DSBGA; MPN BQ25180YBGR; LCSC C3682423

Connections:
+3.3V_PRE: C1.1, D1.2 (A), J2.A2 (SSTXP1), J2.B2 (SSTXP2), R38.1, TP6.1 (1_1), U3.5 (VBUS)
+3V3: C4.1, D3.2 (A), J1.13, J1.14, L2.1, Q1.2 (G1), Q1.5 (G2), Q2.2 (G1), Q2.5 (G2), R3.1, R4.1, R5.1, R20.1, U4.1 (VOUT), U4.10 (FB)
BATTERY_POS: C14.2, IC1.C2 (BAT_1), IC1.C3 (BAT_2), J4.2, U5.C2 (BAT)
BAT_LVL: J1.17, R10.1
BAT_MON_GPIO: IC1.A1 (GPOUT), R10.2, R20.2
BTN_PWR: D4.1 (K), J1.1
D+: J2.A6 (DP1), J2.B6 (DP2), TP5.1 (1_1), U1.6 (I/O1)
D-: J2.A7 (DN1), J2.B7 (DN2), TP4.1 (1_1), U1.4 (I/O2)
GND: C1.2, C2.1, C3.1, C4.2, C7.2, C8.1, C14.1, C15.2, IC1.B2 (VSS_1), IC1.C1 (VSS_2), J1.11, J1.12, J2.A1 (GND_1), J2.A12 (GND_2), J2.B1 (GND_3), J2.B12 (GND_4), J2.MH1, J2.MH2, J2.MH3, J2.MH4, J4.1, P1.A1 (GND), P1.A4 (GND), P1.A7 (GND), P1.B4 (GND), P1.C1 (GND), P1.C7 (GND), R1.2, R2.1, R13.2, R29.1, R38.2, U1.2 (GND), U2.2 (GND), U3.2 (GND), U4.3 (PGND), U4.9 (GND), U4.11 (EP), U4.11_1 (EP), U4.11_2 (EP), U4.11_3 (EP), U4.11_4 (EP), U4.11_5 (EP), U4.11_6 (EP), U4.11_7 (EP), U4.11_8 (EP), U5.D2 (GND)
I2C1_SCL: IC1.A3 (SCL), J1.7, U5.B1 (SCL)
I2C1_SDA: IC1.A2 (SDA), J1.8, U5.C1 (SDA)
N_CLOCK: J2.A3 (SSTXN1), J2.B3 (SSTXN2), TP2.1 (1_1), U2.6 (I/O1)
N_CLOCK_3.3: J1.4, Q1.1 (S1), R4.2
N_CLOCK_SAFE: Q1.6 (D1), R7.2, U2.1 (I/O1)
N_DATA: J2.A11 (SSRXP2), J2.B11 (SSRXP1), TP3.1 (1_1), U3.6 (I/O1)
N_DATA_3.3: J1.6, Q2.3 (D2), R5.2
N_DATA_SAFE: Q2.4 (S2), R8.2, U3.1 (I/O1)
N_LATCH: J2.A10 (SSRXN2), J2.B10 (SSRXN1), TP1.1 (1_1), U2.4 (I/O2)
N_LATCH_3.3: J1.5, Q1.3 (D2), R3.2
N_LATCH_SAFE: Q1.4 (S2), R6.2, U2.3 (I/O2)
unnamed: D4.2 (A), R13.1, U5.D1 (TS/MR)
unnamed: IC1.B1 (BIN), R29.2
unnamed: C15.1, IC1.B3 (VDD)
unnamed: J2.A5 (CC1), R2.2
unnamed: J2.B5 (CC2), R1.1
unnamed: P1.A6 (DO), R14.2
unnamed: P1.B3 (IRQ), R12.1
unnamed: C3.2, R9.2, U4.6 (EN), U4.7 (PS/SYNC), U4.8 (VINA)
unnamed: L1.1, U4.4 (L1)
unnamed: L1.2, U4.2 (L2)
SAFE_D+: J1.15, U1.1 (I/O1)
SAFE_D-: J1.16, U1.3 (I/O2)
SHARED_PU: D3.1 (K), R6.1, R7.1, R8.1
VBUS: C7.1, J2.A4 (VBUS_1), J2.A9 (VBUS_2), J2.B4 (VBUS_3), J2.B9 (VBUS_4), TP7.1 (1_1), U1.5 (VBUS), U5.A2 (IN)
VBUS_SYS: C2.2, C8.2, D1.1 (K), R9.1, U4.5 (VIN), U5.B2 (SYS)
VDDBAT: L2.2, P1.B7 (VDDIO), P1.C2 (VDDBAT)
WL_CLK: J1.3, P1.A3 (SCLK)
WL_CS: J1.2, P1.B2 (CS)
WL_D: J1.9, P1.A5 (DI), R12.2, R14.1
WL_GP0: P1.B1 (GPIO0)
WL_GP1: P1.C4 (GPIO1)
WL_GP2: P1.C3 (GPIO2)
WL_ON: J1.10, P1.B5 (WLON), P1.B6 (BTON)

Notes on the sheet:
Level Shifters
LiPo Battery Circuit
Battery PMIC
ESD
Power Bus
Bluetooth Build Specific Components These components are used in Bluetooth capable assemblies.
RPI-RM2 Wireless

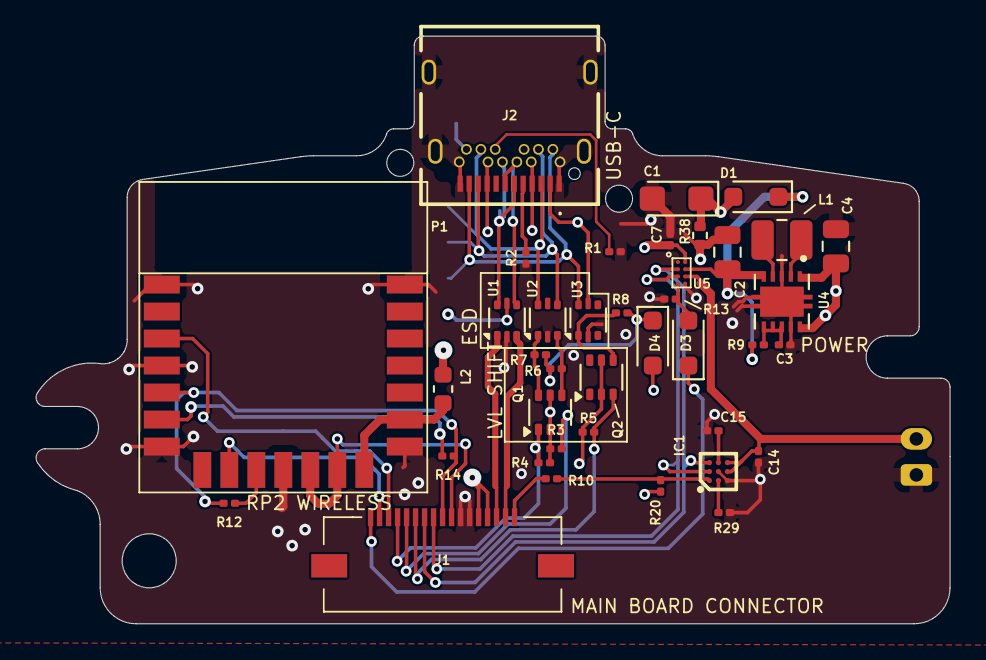
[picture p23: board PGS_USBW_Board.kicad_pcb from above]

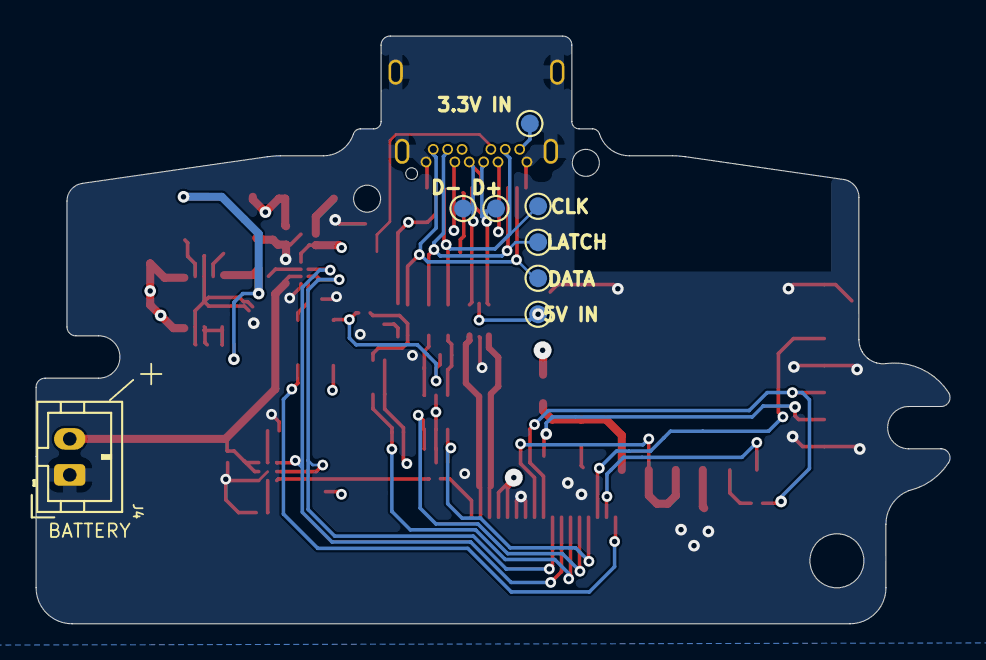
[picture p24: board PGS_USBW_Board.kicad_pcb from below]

Board: 4 copper layers, 50.8 x 32.6 mm, 47 parts (8 on the bottom side), 40 nets.

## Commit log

2025-05-15 Initial progress commit
    [Main_Board_Export.dxf, PGS_Main_Board.kicad_pcb, PGS_Main_Board.kicad_sch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]
2025-05-16 PCB Routing
    [PGS_Main_Board.kicad_pcb, PGS_Main_Board.kicad_sch]
2025-05-16 Routing update
    [PGS_Main_Board.kicad_pcb, PGS_Main_Board.kicad_sch]
2025-05-16 More Routing
    [PGS_Main_Board.kicad_pcb, PGS_Main_Board.kicad_sch]
2025-05-17 Board Pos Fixes
    - Fix RGB Resistor position
    - Move input matrix diode arrays
    - Move conflicting LRA driver components
    [PGS_Main_Board.kicad_pcb]
2025-05-18 More Routing
    - Stick Module Done
    - BT Comms + Power Done
    [PGS_Main_Board.kicad_pcb, PGS_Stick_Board.kicad_pcb, PGS_Stick_Board.kicad_sch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]
2025-05-18 Final Routing 3D Export
    - Export 3D STEP models
    [PGS_Main_Board.kicad_pcb, PGS_Stick_Board.kicad_pcb, PGS_Stick_Board.step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]
2025-05-18 Board Fixes
    - Relocate RGB on main board to align with pass-through holes
    - Exchange battery connector for through-hole battery JST connector and change pcb shape
    - New interactive BOM with PCB previews
    [PGS_Main_Board-B_Cu.gbr, PGS_Main_Board-B_Mask.gbr, PGS_Main_Board-B_Paste.gbr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]
2025-05-19 Add and Organize 3D Files
    [Button.iges, Button.step, DPad.iges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]
2025-05-19 Reorganize files
    [LowerMenu.iges, LowerMenu.step, PowerButton.iges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]
2025-05-19 Fix Shell Tolerance
    [TopShell.step]
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2025-05-20 Fixes to top shell
    - Top shell was off center Y axis
    - Fixed up top shell
    - Fixed other out of alignment items
    [TopShell.step, TriggerHolder.iges, TriggerHolder.step]
2025-05-20 Add Standoffs
    - Add posts for main PCB support from mid shell
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2025-05-20 Button Cutouts
    Change opening to 0.18mm on top shell for ABXY
    0.20 for DPad
    [TopShell.step]
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2025-05-20 Tolerance Updates
    M3 screws have a 4.25mm offset for all shell parts
    Plastic screw holes all normalized to 1.65mm for better fitment
    [TopShell.step, TriggerHolder.iges, TriggerHolder.step]
2025-07-11 Update Trigger Module
    [PGS_Trigger_Board-B_Cu.gbr, PGS_Trigger_Board-B_Mask.gbr, PGS_Trigger_Board-B_Paste.gbr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]
2025-07-20 Main Board Update
    - Put 1uF caps closer to designated pins
    - Update timestamp on PCB mask
    [PGS_Main_Board-B_Cu.gbr, PGS_Main_Board-B_Mask.gbr, PGS_Main_Board-B_Paste.gbr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]
2025-07-21 Annotate schematic
    1uF capacitor annotation updated for main PCB
    [PGS_Main_Board.kicad_sch]
2025-08-04 Membrane Thickness increase
    - Silicone membrane actuator thickness increased from 0.15mm -> 0.4mm
    [DpadSilicone.iges, DpadSilicone.step, MainButtonSilicone.iges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]
2025-08-19 CAD Updates
    - ABXY Button updated to have unique heights per-button to match the shell profile.
    [Button.iges, Button.step, Button_East.iges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]
2025-09-02 USBW Update
    - Implement fuel gauge IC
    [PGS_Main_Board.kicad_sch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]
2025-09-02 Change font for plus symbol
    [PGS_USBW_Board.kicad_pcb]
2025-09-23 Main Board/Trigger Board Update
    - Main board updated with Kailh tactile switches
    - Trigger board updated with Kailh tactile switches
    - USBW board updated to remove unneeded diode, move position of USB-C port
    [PGS_Main_Board-B_Cu.gbr, PGS_Main_Board-B_Mask.gbr, PGS_Main_Board-B_Paste.gbr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]
2025-09-23 USB C Port Adjustment
    - Spacing between USB C port and USB C cable adjusted
    [PGS_USBW_Board-B_Cu.gbr, PGS_USBW_Board-B_Mask.gbr, PGS_USBW_Board-B_Paste.gbr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]
2025-09-24 USB-C Adjustment
    Adjusted USB-C port to have 0.3mm clearance between shell and overmold on the USB-C cable
    [PGS_USBW_Board-B_Cu.gbr, PGS_USBW_Board-B_Mask.gbr, PGS_USBW_Board-B_Paste.gbr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]
2025-09-29 CAD Updates
    - Trigger updates
    - Rear grip updates
    - Gateplate updates
    - Shell Updates
    [Button_East.iges, Button_East.step, Button_North.iges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]
2025-10-09 Grip button adjustments
    - Make custom silicone pad
    [GL.iges, GL.step, GR.iges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]
2025-10-16 Update joystick
    Increase depth of shaft female portion by 0.2mm
    [FullStick.iges, FullStick.step, PlasticPart.iges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]
2026-09-18 Sept 2026 Changes
    [Button_East.iges, Button_East.step, Button_North.iges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]
2026-09-19 Routing Changes
    [PGS_Main_Board.kicad_pcb, PGS_Main_Board.kicad_sch]
2026-09-22 Sync local board work; replace Trigger Board with Trigger FPC
    - Update Main, Stick and USBW board layouts, schematics and 3D exports
    - Replace the rigid Trigger Board project with the new Trigger FPC design
    - Add shared PCB/Libraries footprint library and fp-lib-table
    - Regenerate production outputs (gerbers, drills, placement, BOM) for all boards
    - Stop tracking KiCad auto-backup folders and fp-info-cache; consolidate .gitignore
    [FPC_Trigger_Board-B_Cu.gbl, FPC_Trigger_Board-B_Mask.gbs, FPC_Trigger_Board-B_Paste.gbp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]
2026-09-22 Trigger flex
    [Button East Body.stl, Button North Body.stl, Button South Body.stl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]
2026-09-22 Create Player Lightpipe.stl
    [Player Lightpipe.stl]
2026-09-25 STL updates
    [Button East Body.stl, Button North Body.stl, Button South Body.stl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]
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2026-10-11 Consolidate custom symbols, footprints and 3D models into repo library
    Make the hardware repo self-contained instead of depending on the external
    HHL-KiCad-Lib checkout and the missing progcc_v3 symbol library.
    - New PCB/Libraries/ProGCC 4 Library.kicad_sym: the 12 custom symbols,
    extracted from the schematics' embedded caches (identical to what the
    boards use; duplicate hhl/progcc_v3 CUS08F30 merged)
    - Library.pretty: add the 7 missing footprints and replace 9 that differed
    from the placed footprints with the hhl copies the boards match
    - PCB/Libraries/3dmodels: STEP models previously referenced by absolute
    path into HHL-KiCad-Lib, now via ${KIPRJMOD}/../../Libraries/3dmodels
    - Rel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
2026-10-11 Add HAL4395 symbol and swap it in for the hall sensors
    New ProGCC 4 Library:HAL4395 (1 VCC, 2 ~EN, 3 GND, 4 NC, 5 OUT tri-state),
    geometry identical to the patched placeholder so no wiring changes.
    Replaces Regulator_Linear:TLV70012_SOT23-5 on the 8 Main and 4 Trigger FPC
    halls. Clears the hall lib_symbol_mismatch warnings and the shared-ADC
    output-to-output pin conflicts. Netlist unchanged (checked against kicad-cli).
2026-10-11 Main: ERC cleanup and PWR_FLAGs
    - No-connect flags on unused RP2354B pins (GPIO22-27, GPIO36-39, QSPI
    SD0-3/SCLK; flash is internal) and on RGB2/4/6/8 DOUT (paired LEDs).
    - Remove the dangling wire stubs on GPIO36-38.
    - PWR_FLAGs on GND, +3V3 (from J9), +1V1 (VREG via L1) and VREG_AVDD
    (via R11).
    - ST_LSM6: VDD/VDDIO/GND/GNDIO retyped bidirectional -> power_in.
    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
2026-10-11 USBW: ERC cleanup and GND PWR_FLAG
    - No-connect flags on U3 unused channel (pins 3/4), BQ25180 /INT,
    USB-C SBU1/SBU2, and the spare Q2A FET (S1/D1).
    - Remove dangling stubs on U3 pins 3/4 and the tails past Q1A pins 1/6.
    - Pin types (library + embedded): TPS63000 VOUT output -> power_out
    (it drives +3V3), BQ25180 /INT input -> open_collector, RPI-RM2
    WL_GPIO0-2 input -> bidirectional.
    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
2026-10-11 BOM fields: fill missing MPN/LCSC, drop empty legacy fields
    - Main: MPN/LCSC for R1/R28/R29 (1k), R5/R6 (10k), R7/R8 (100R),
    R11 (33R, RC0201FR-0733RL / C295794) and R9/R10 (10R). R9/R10's Link
    pointed at the 0R jumper (C106227); corrected to RC0201FR-0710RL /
    C106226 to match the 10R value.
    - USBW: R38 Manufacturer YAGEO; trim trailing whitespace on 9 MPNs.
    - Trigger FPC: J1/J2 are the ribbon-tail fingers, not purchased parts;
    exclude from BOM and position files.
    - All boards: remove properties with empty values (Manufacturer_Name,
    Mouser fields, Height, JLCPN, PART_REV, etc.). Populated fields and
    the standard/core fields are untouched.
    SW1 (GuliKit stick) and P1 (RM2) have no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
2026-10-11 Main PCB: update from schematic
    Fields and pin types only; no footprints, tracks, vias, zones or nets
    changed (120 footprints, identical reference list and pad nets).
    - HAL4395 description and tri-state OUT pin type on the 8 halls.
    - Pin types synced (RP2354B NC pins, IMU power pins, RGB DOUT).
    - R9/R10 Link corrected to the 10R part.
    - Stale PCB data synced from schematic: R15/R26 MPN/LCSC (27R),
    J7 value 505110-0592, J7/J11 LCSC.
    - Empty legacy fields removed.
    DRC 238 -> 223 (the 15 schematic-parity mismatches cleared; all other
    categories unchanged).
2026-10-11 USBW: fix TPS63000 EP pins and test-point position-file flags
    - TPS63000DRCR: remove stacked pins 11_1..11_8 (library + embedded +
    U4 instance). The VREG_V62_16624-01YE footprint has a single custom
    EP pad "11", so these caused "pad not found" errors on PCB update.
    They sat on pin 11, so connectivity is unchanged (EP still on GND).
    - TP1-TP7: in_pos_files no, matching the PCB. Otherwise the update
    would strip the PCB's position-file exclusion.
    ERC unchanged (5). Netlist matches kicad-cli.
2026-10-11 USBW PCB: update from schematic
    changed (47 footprints, identical reference list and pad nets).
    - R38 MPN/LCSC/Manufacturer; trailing whitespace trimmed on 9 MPNs.
    - Pin types synced (TPS63000 VOUT power_out, BQ25180 /INT, RM2 GPIOs,
    NC pins on J2/Q2/U3).
    - Empty legacy fields removed; TP1-TP7 keep BOM/position exclusions.
    DRC 138 -> 99 (the 39 schematic-parity mismatches cleared; all other
    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
2026-10-11 Trigger FPC PCB: update from schematic
    Fields and attributes only; no footprints, tracks, vias, zones or nets
    changed (10 footprints, identical reference list and pad nets).
    - U1-U4: HAL4395 description and tri-state OUT pin type.
    - J1/J2 (ribbon-tail fingers): exclude from BOM and position files,
    plus DNP (already set in the schematic; the PCB had never picked it
    up). Copper is unaffected.
    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
2026-10-11 Stick: correct C1/C2 package and description
    MPN CC0402KRX7R9BB473 / LCSC C272875 is YAGEO 0402, 47nF, ±10%, 50V,
    X7R (LCSC listing; K = ±10%, 9 = 50V in YAGEO CC ordering codes), which
    matches the 0402 footprint. The Package field said 0603 and the
    descriptions said 0603 (C1 also ±5%); now "0402" and
    "CAP CER 47nF 50V X7R ±10% 0402".
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2026-10-11 Stick PCB: fix DRC errors (short, outline, dangling via, clearance)
    - Delete an orphan OUT_Y track stub between C1's pads that shorted
    OUT_Y to GND (also the solder-mask bridge). OUT_Y still reaches C1
    pad 2 via its existing track.
    - Delete a 17 nm Edge.Cuts segment and close the 17 nm gap by moving
    the adjoining line's endpoint (malformed outline).
    - Delete the dangling +3V3 via at (59.225, 56.525); its two F.Cu tracks
    already meet there.
    - Default net class clearance 0.2 -> 0.15 mm so the stock 0201
    footprints (0.18 mm pad gap) pass; Main uses 0.1 mm.
    DRC 22 -> 16 (with zone refill). Remaining: J1 MP2 tab edge clearance
    (accepted), J1 silk clipped by edge, R1/R2 library mismatch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
2026-10-11 Stick PCB: refill zones, exclude J1 MP2 edge clearance
    - GND zone refilled after removing the stub and dangling via.
    - DRC exclusion for J1 MP2 (unconnected FPC-connector solder tab,
    0.04 mm from the board edge): accepted as-is.
    DRC now reports 0 errors. Remaining warnings: J1 silk clipped by the
    edge (3), R1/R2 library mismatch (2), text height (10).
2026-10-11 Trigger FPC: fix U2/ADC_2 clearance, allow FPC fingers at the edge
    - ADC_2 ran 0.133 mm from U2 pad 2 (rule 0.15): U2's pads sit 0.125 mm
    off the original routing. Add a jog through the pad-1/pad-2 midline
    (x 241.408) and back to x 241.8 below the pads; min clearance now
    ~0.20 mm.
    - New FPC_Trigger_Board.kicad_dru: edge_clearance min 0 for the
    "505110-0592 Ribbon" footprint, since the contact fingers must run
    to the edge to mate with the Main board connectors.
    DRC errors 12 -> 0 (with zone refill). Remaining warnings: floating
    B.Cu pour (2), 0201 lib mismatch (4), silk clipped (2), text height (8).
    Zones need a refill in KiCad.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
2026-10-11 Trigger FPC: ground the back pours with stitching vias, refill zones
    Add 2 GND and 2 GNDL vias (0.6/0.3) in the sensor areas so the hatched
    B.Cu pours are tied to ground instead of floating. Zones refilled.
    DRC: 0 errors, isolated-copper warnings cleared. Remaining warnings
    are cosmetic: 0201 lib mismatch (4), silk clipped (2), text height (8).
2026-10-11 USBW: allow the USB-C land pattern's 0.236 mm pad-to-peg hole clearance
    New PGS_USBW_Board.kicad_dru: hole_clearance min 0.2 mm between items of
    the GCT USB4056-03-A (J2) footprint only, whose manufacturer land pattern
    puts pad A12 0.236 mm from the NPTH alignment peg. The 0.25 mm board rule
    still applies everywhere else.
    DRC: 0 errors. Remaining 98 warnings are silkscreen/text/library-copy
    cosmetics.
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2026-10-11 USBW PCB: update footprints from library
    - All 29 footprints flagged as differing from their library copy updated
    to the KiCad 10 versions (courtyard/fab redraws, library 3D model paths
    instead of embedded copies). Q1/Q2 SOT-363 now use KiCad 10's larger
    land pattern; C1 tantalum pads grew slightly.
    - The larger Q1 pad 5 came within 0.097 mm of a SHARED_PU via; moved the
    via 0.08 mm away (to 69.3166, 36.65) with its two tracks.
    - Footprint fields re-synced from the schematic (the library update had
    renamed one field per part to KiLib_Generator).
    No parts moved, no net changes. DRC: 0 errors, 0 library mismatches,
    0 field mismatches; 66 cosmetic silk/text warnings remain.
    Co-Autho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
2026-10-11 Main PCB: fix mask bridges, broken courtyards and drill rule
    - New PGS_Main_Board.kicad_dru: keep the GND pour 0.15 mm from the JST
    SM02B haptics pads (J1/J2). Their 0.102 mm solder-mask margin exceeded
    the 0.1 mm pour clearance, exposing GND inside the LRA pad openings
    (4 solder-mask-bridge errors). Takes effect on zone refill.
    - 5051100592 footprint (library + J7/J11): every courtyard line was
    duplicated, giving 21-22 malformed-courtyard errors. Removed the
    duplicates.
    - Minimum through-hole diameter 0.3 -> 0.25 mm (U2's 0.25 mm thermal vias).
    DRC errors 44 -> 10 (with refill). Remaining: SW9 edge clearance and
    5 courtyard overlaps (checked: no physical clash), 4 starved thermal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
2026-10-11 Main PCB: refill zones, GND stubs for starved thermals, DRC exclusions
    - Zones refilled (applies the JST haptics-pad pour clearance rule).
    - Short GND tracks from C9, C12, C27, C37 to nearby GND pads / pour.
    - DRC exclusions (all reviewed): SW9 pad 2 edge clearance (accepted),
    courtyard overlaps J3-U3, J5-U10, J11-Y1, C23-Y1, R1-Y1 (no body or
    pad clash), starved thermals C9 and C12.
    DRC: 0 errors, no unconnected items.
2026-10-11 Trigger FPC PCB: update footprints from library
    C1-C4 (0201) updated to the KiCad 10 library versions; fields re-synced
    from the schematic. No parts moved, no track/via/net changes.
    DRC: 0 errors, 0 library mismatches.
2026-10-11 Stick PCB: update footprints from library; J1 tab edge rule
    - R1/R2 (0201) updated to the KiCad 10 library versions; fields
    re-synced from the schematic. No parts moved, no track/via/net changes.
    - The update re-encoded J1's MP2 pad rotation (no physical change),
    which moved the DRC marker and orphaned its exclusion. Replaced the
    exclusion with PGS_Stick_Board.kicad_dru: edge_clearance min 0 for
    J1 pad MP2 only (accepted earlier; survives future updates).
    DRC: 0 errors, 0 library mismatches, no exclusions.
